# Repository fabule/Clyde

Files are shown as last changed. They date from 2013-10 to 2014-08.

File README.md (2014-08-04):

Clyde
======
Clyde is a lamp with a lot of personality that you can adapt, play with, and truly call your own. Clyde is open source and Arduino-compatible.  You can change how Clyde reacts to his environment by inserting personality modules on his main controller board. You can also change how Clyde behaves by reprogramming his firmware using the standard Arduino IDE.

For more information, see the website at: http://www.fabule.com or the forum at: http://fabule.com/forum/

To report a bug in the hardware or software, go to:
http://github.com/fabule/Clyde/issues

Installation
------------

The Clyde firmware is divided into three parts: bootloader, library, and sketch.

You can find the Clyde library in /software/arduino/libraries/. Place the "Clyde" library folder inside your Arduino "librairies" folder. This contains the majority of the code that controls Clyde. If you are not sure about how to install an Arduino library, you can find instructions here: http://arduino.cc/en/Guide/Libraries

When the library is in place, you can look for the sketch in /software/arduino/libraries/Clyde/Examples/ClydeOriginal. This sketch does not contain much, but it is a good place to start playing with Clyde's behaviors.

If you are using Windows, you'll need to install Clyde's driver. Find installers for 32-bit and 64-bit in /software/arduino/drivers/.  Double-click the driver that matches your needs.

Before you open your Arduino IDE, you'll need to copy one more folder. This step will add Clyde as a device under the "Tools > Board menu". First, if you do not have a "hardware" folder at the same level as your Arduino "librairies" folder, time to create one. Browse to the "hardware" folder in /software/arduino/hardware/ and open the subfolder that matches the version of your Arduino IDE, 1.0.5 or 1.5. Inside you'll find a "fabule" folder. Copy the "fabule" folder, inside the Arduino "hardware" folder you just created.

At this point, you should be ready to compile and upload Clyde's firmware. Connect Clyde to your computer using the USB cable.  Open the "ClydeFirmware" sketch in your Arduino IDE under "File > Examples > Clyde > ClydeOriginal" . Select Clyde under the "Tools > Board" menu, and the port assigned to Clyde under "Tools > Serial" Port. Press "Upload", and the firmware should compile and upload into Clyde.

If you want to make modifications to the bootloader, please refer to the information found here: https://github.com/fabule/Clyde/tree/master/software/arduino/bootloaders/caterina

Credits
-------
Clyde is an open source project manage by Fabule Fabrications in Montréal, Québec, Canada.

Clyde is based on the Arduino project, see the website at: http://arduino.cc

Arduino uses the GNU avr-gcc toolchain, avrdude, avr-libc, and code from
Processing and Wiring, LUFA, and i2cdevlib.

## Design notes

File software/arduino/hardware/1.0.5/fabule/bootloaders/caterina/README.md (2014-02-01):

Clyde Bootloader
================

How-To Compile
--------------
* Download and extract LUFA: https://code.google.com/p/lufa-lib/downloads/detail?name=LUFA-111009.zip&can=2&q=
* Set your LUFA directory in the Makefile.
* Run: make clyde

How-To Program
--------------
* Set your AVRDUDE_PROGRAMMER and AVRDUDE_PORT in the Makefile
* Run: make program
* (on Windows) You'll need to point to the .inf file found in /software/arduino/drivers

Changes
-------
* Added "Fabule" and "Clyde" to the USB descriptor strings of Descriptor.c
* Added a "clyde" target to the Makefile to speed up the compiling process
* Changed the "program" target of the Makefile to accept product ids for hex file selection

Attribution
-----------
This Clyde bootloader is based on the Arduino Caterina bootloader in release 1.0.5 found at:
https://github.com/arduino/Arduino/releases/tag/1.0.5

This bootloader, just like the original Caterina, uses the LUFA library found at:
https://code.google.com/p/lufa-lib/
more specifically, it was tested with the "111009" release of LUFA found at:
https://code.google.com/p/lufa-lib/downloads/detail?name=LUFA-111009.zip&can=2&q=

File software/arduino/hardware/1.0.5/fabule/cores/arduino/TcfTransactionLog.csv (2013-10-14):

Service | Message | Max | Min | Average | Count | frequency | TimedOut
Stream | setLogBits | 458 | 79 | 268.5 | 2 | 0

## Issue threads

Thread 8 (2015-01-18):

Mouth?

bruno-c, 2015-01-18:
Hello,

I see a bunch of references to a Clyde loud mouth in the code! I assume this is a feature that didn't make it into Mark 1, but would it be hard to add some kind of audio output to Clyde? I don't have any experience with Arduino, though I have plenty of programming experience.

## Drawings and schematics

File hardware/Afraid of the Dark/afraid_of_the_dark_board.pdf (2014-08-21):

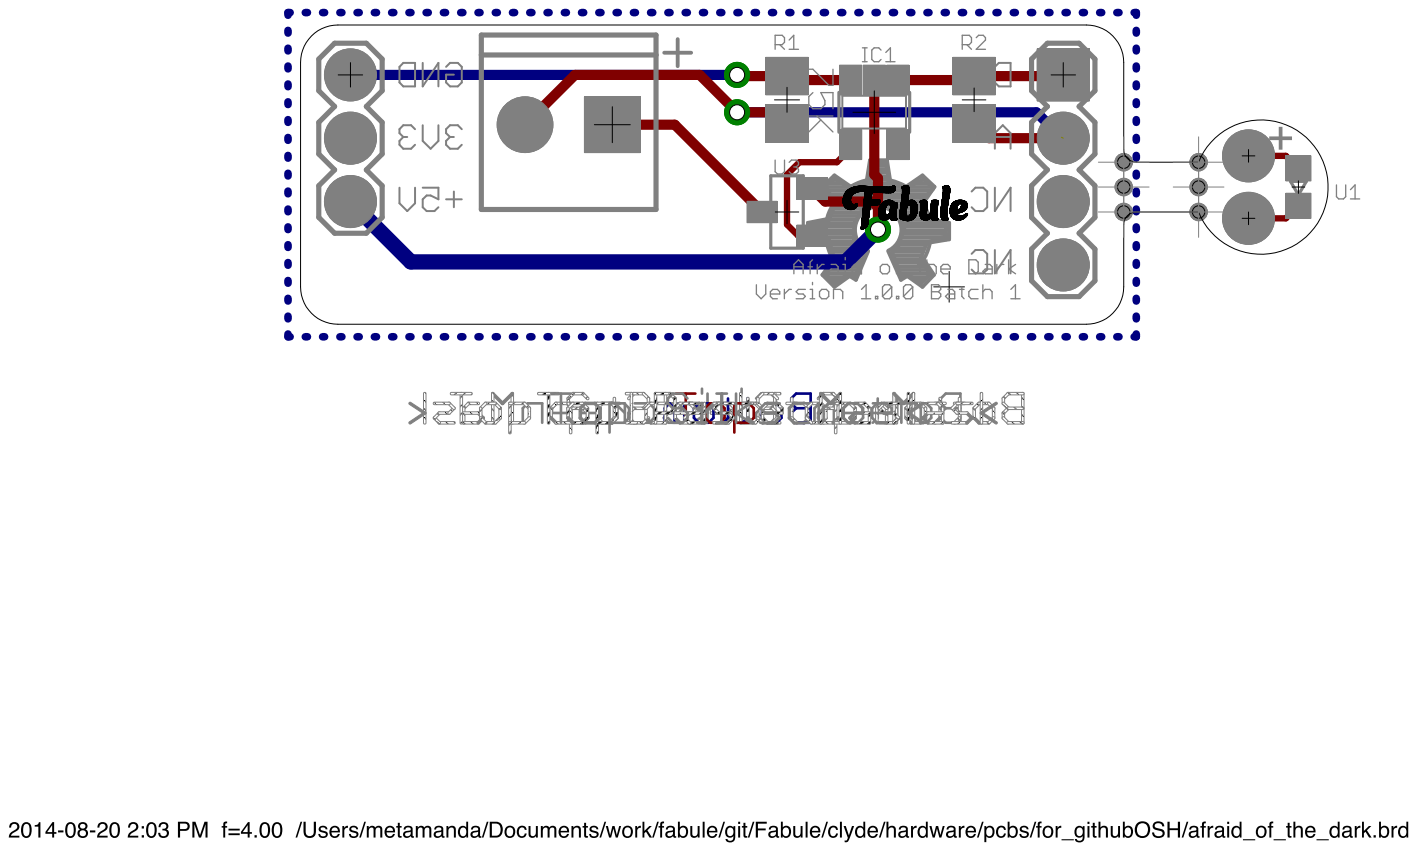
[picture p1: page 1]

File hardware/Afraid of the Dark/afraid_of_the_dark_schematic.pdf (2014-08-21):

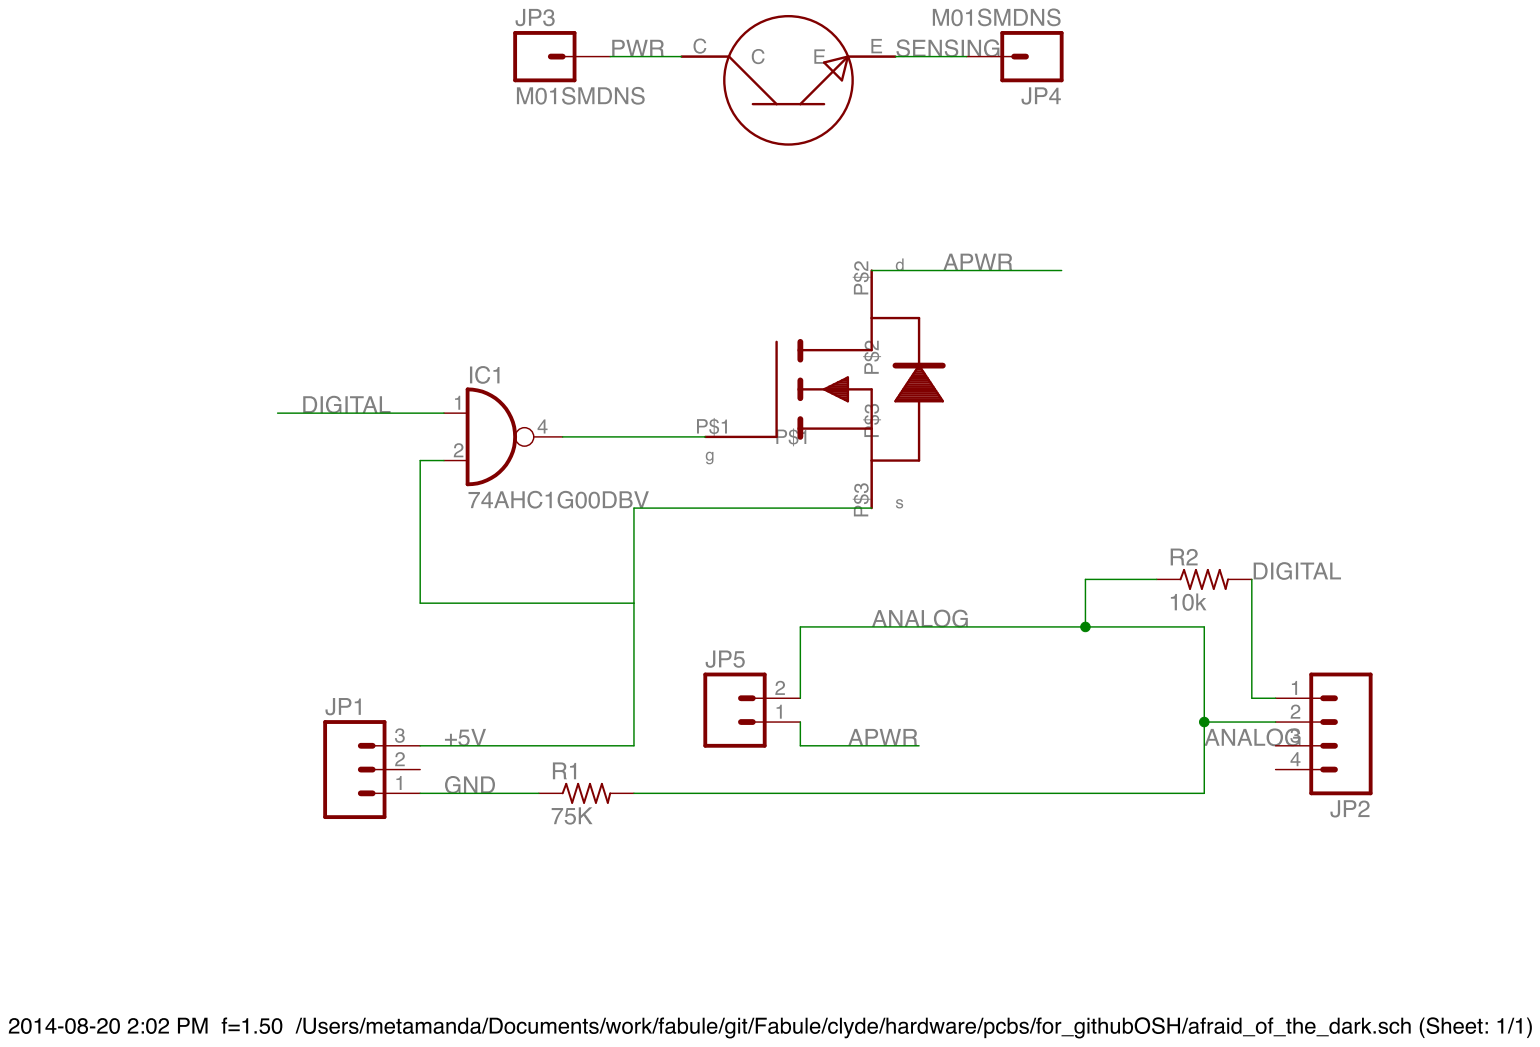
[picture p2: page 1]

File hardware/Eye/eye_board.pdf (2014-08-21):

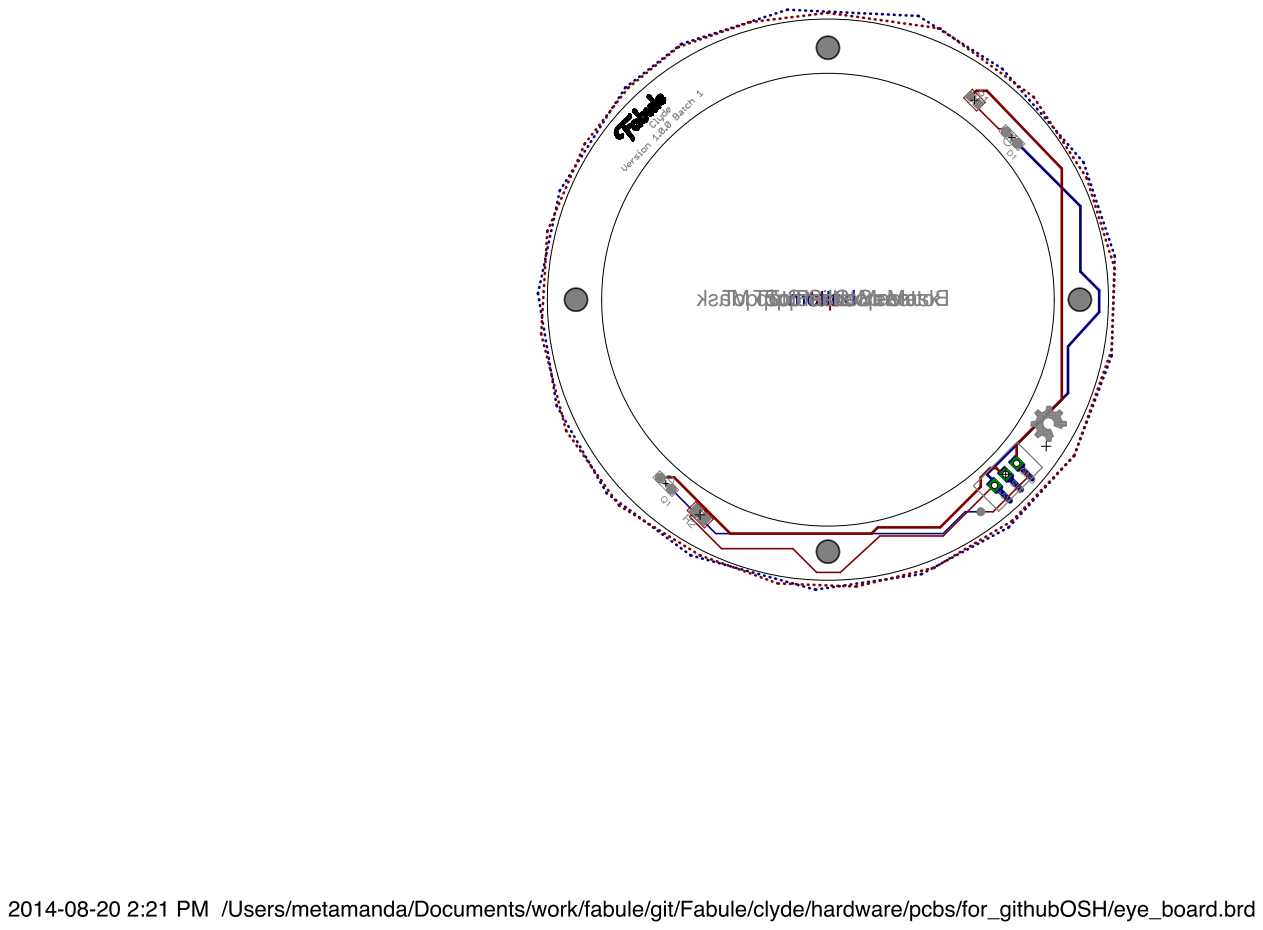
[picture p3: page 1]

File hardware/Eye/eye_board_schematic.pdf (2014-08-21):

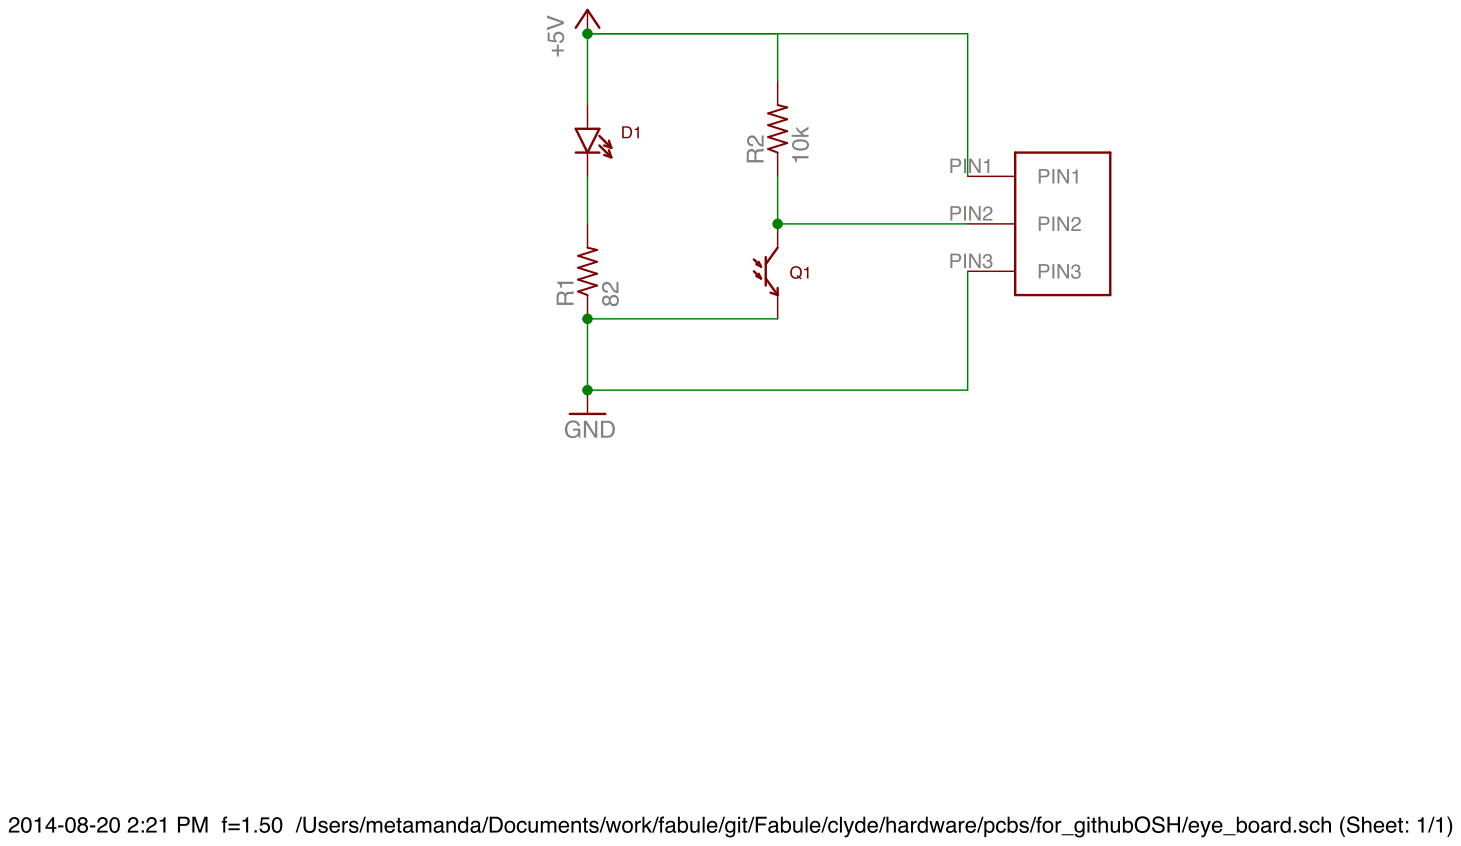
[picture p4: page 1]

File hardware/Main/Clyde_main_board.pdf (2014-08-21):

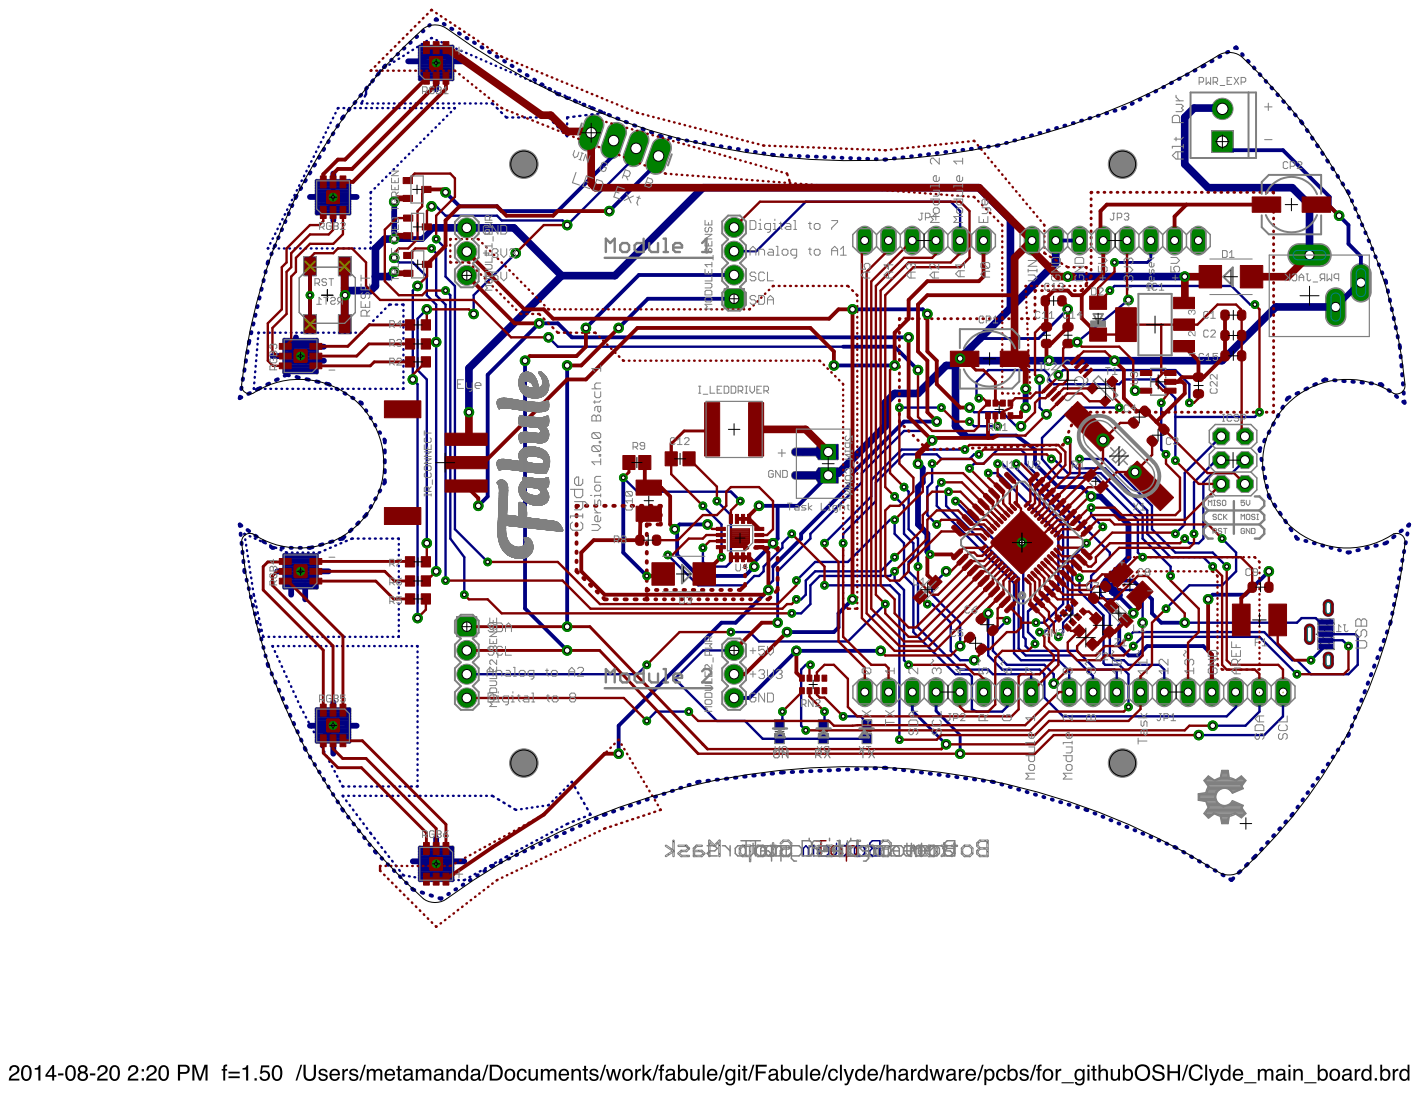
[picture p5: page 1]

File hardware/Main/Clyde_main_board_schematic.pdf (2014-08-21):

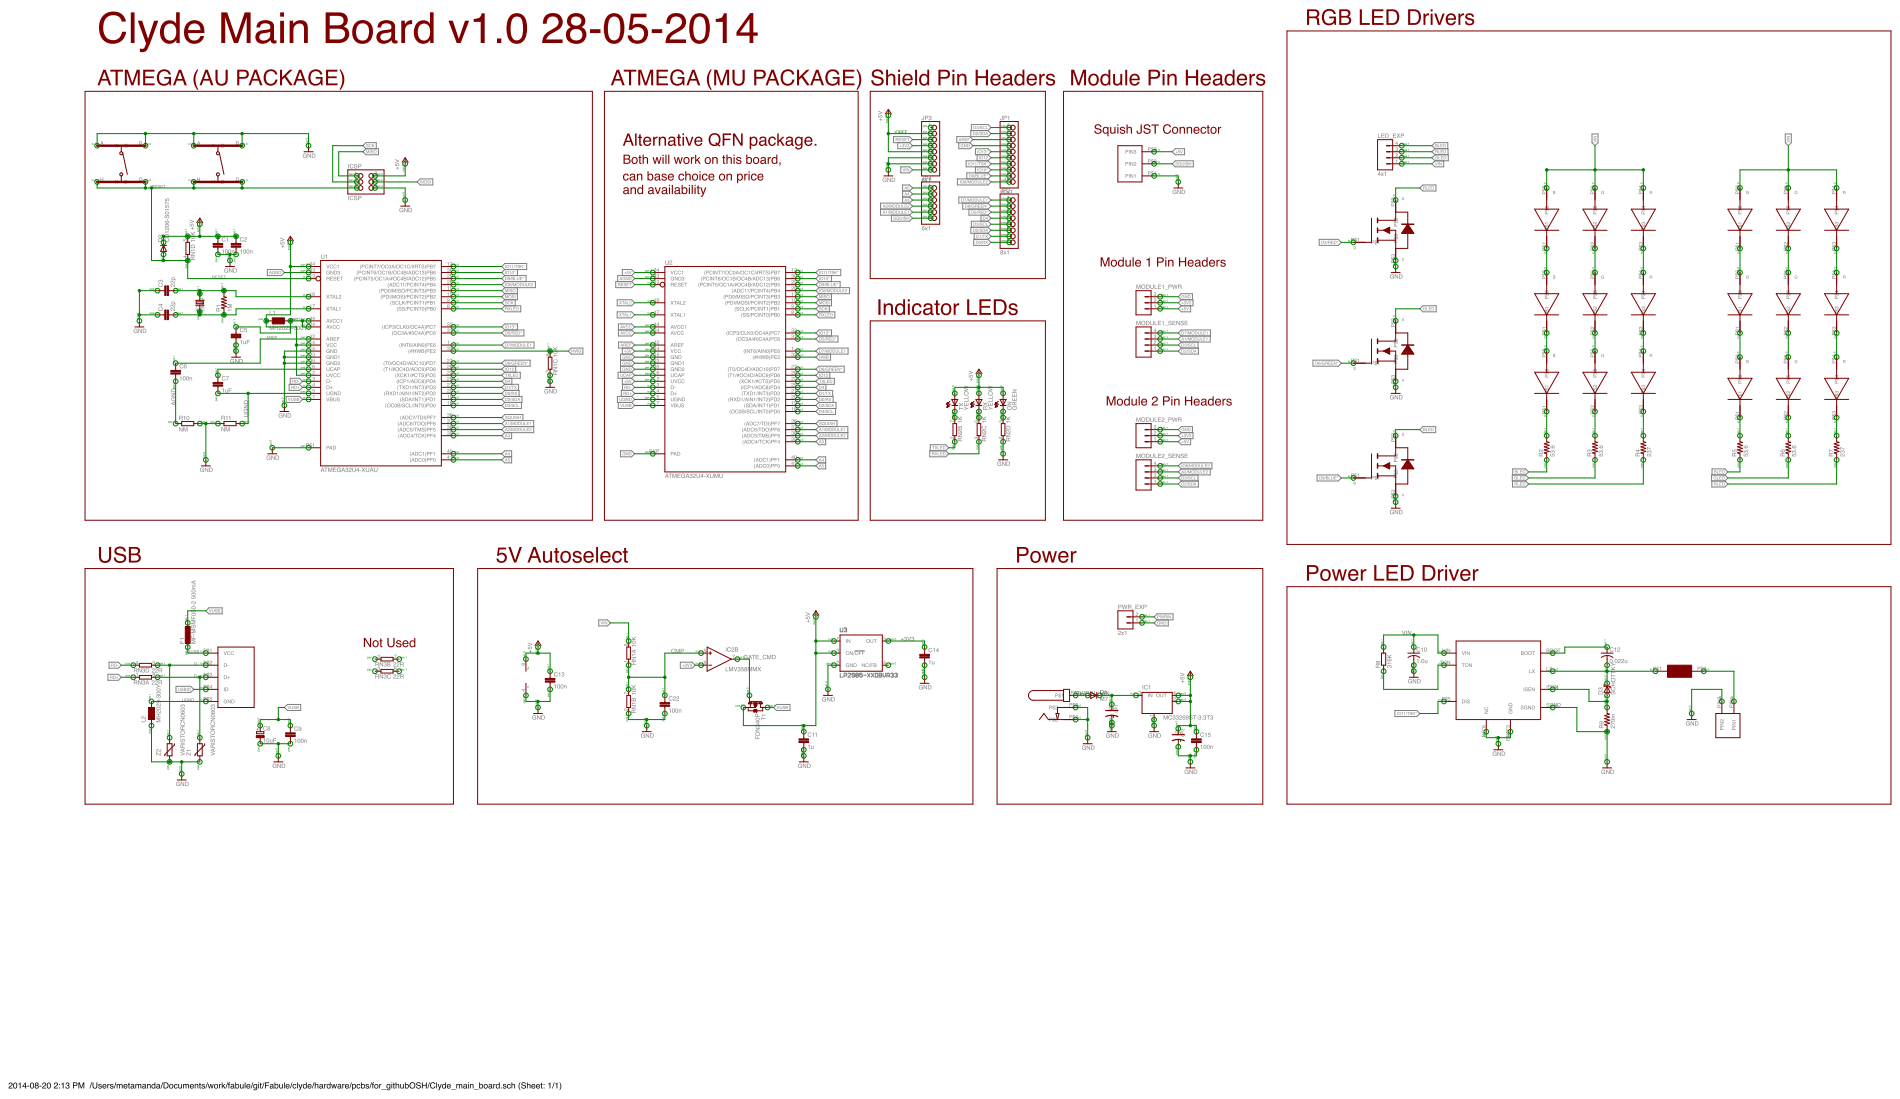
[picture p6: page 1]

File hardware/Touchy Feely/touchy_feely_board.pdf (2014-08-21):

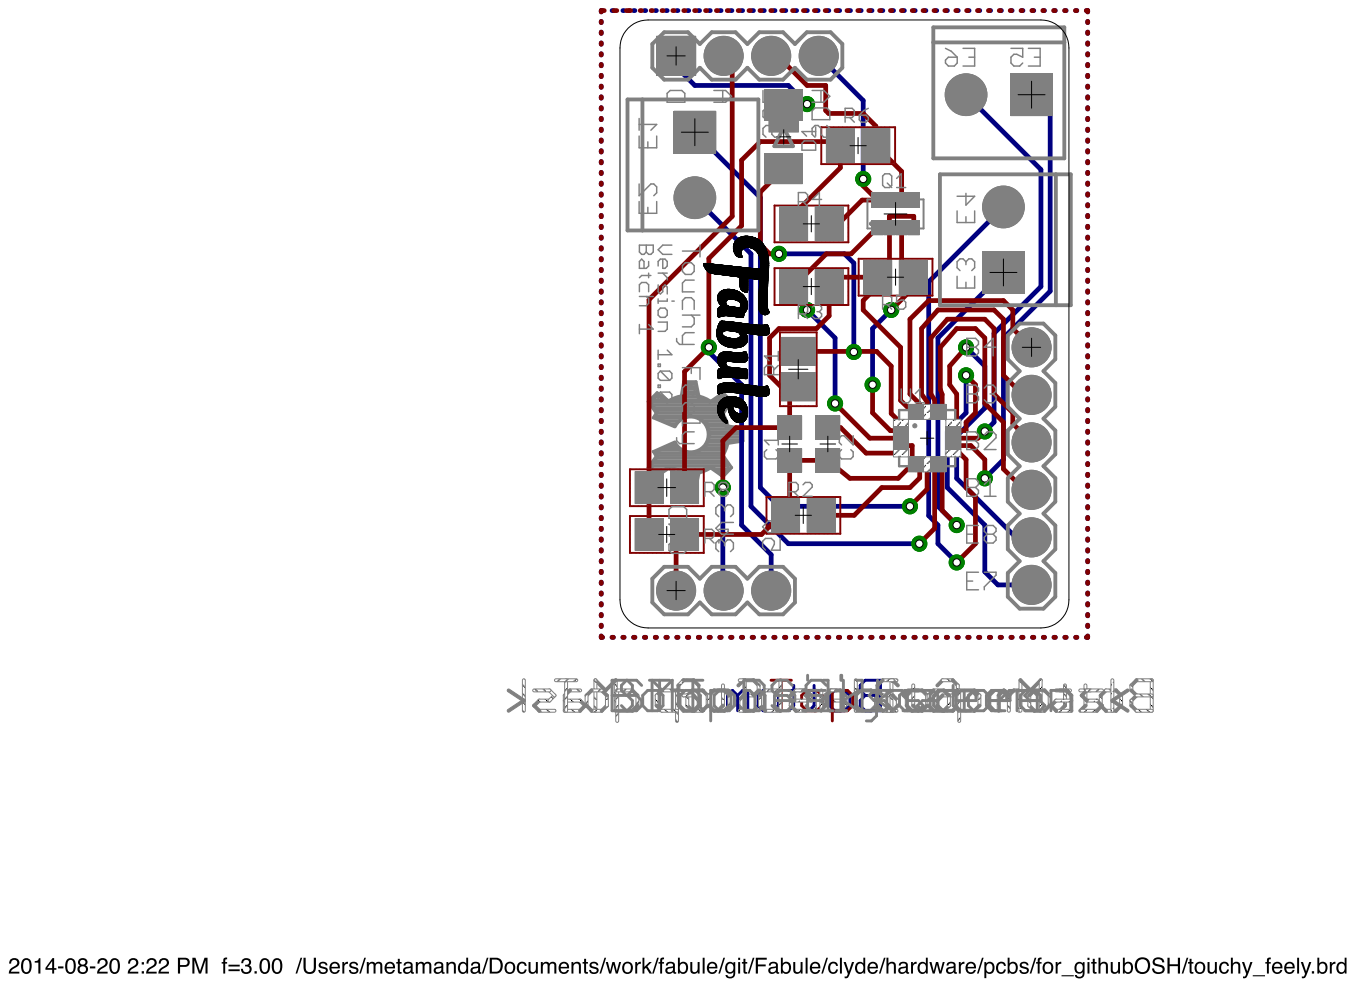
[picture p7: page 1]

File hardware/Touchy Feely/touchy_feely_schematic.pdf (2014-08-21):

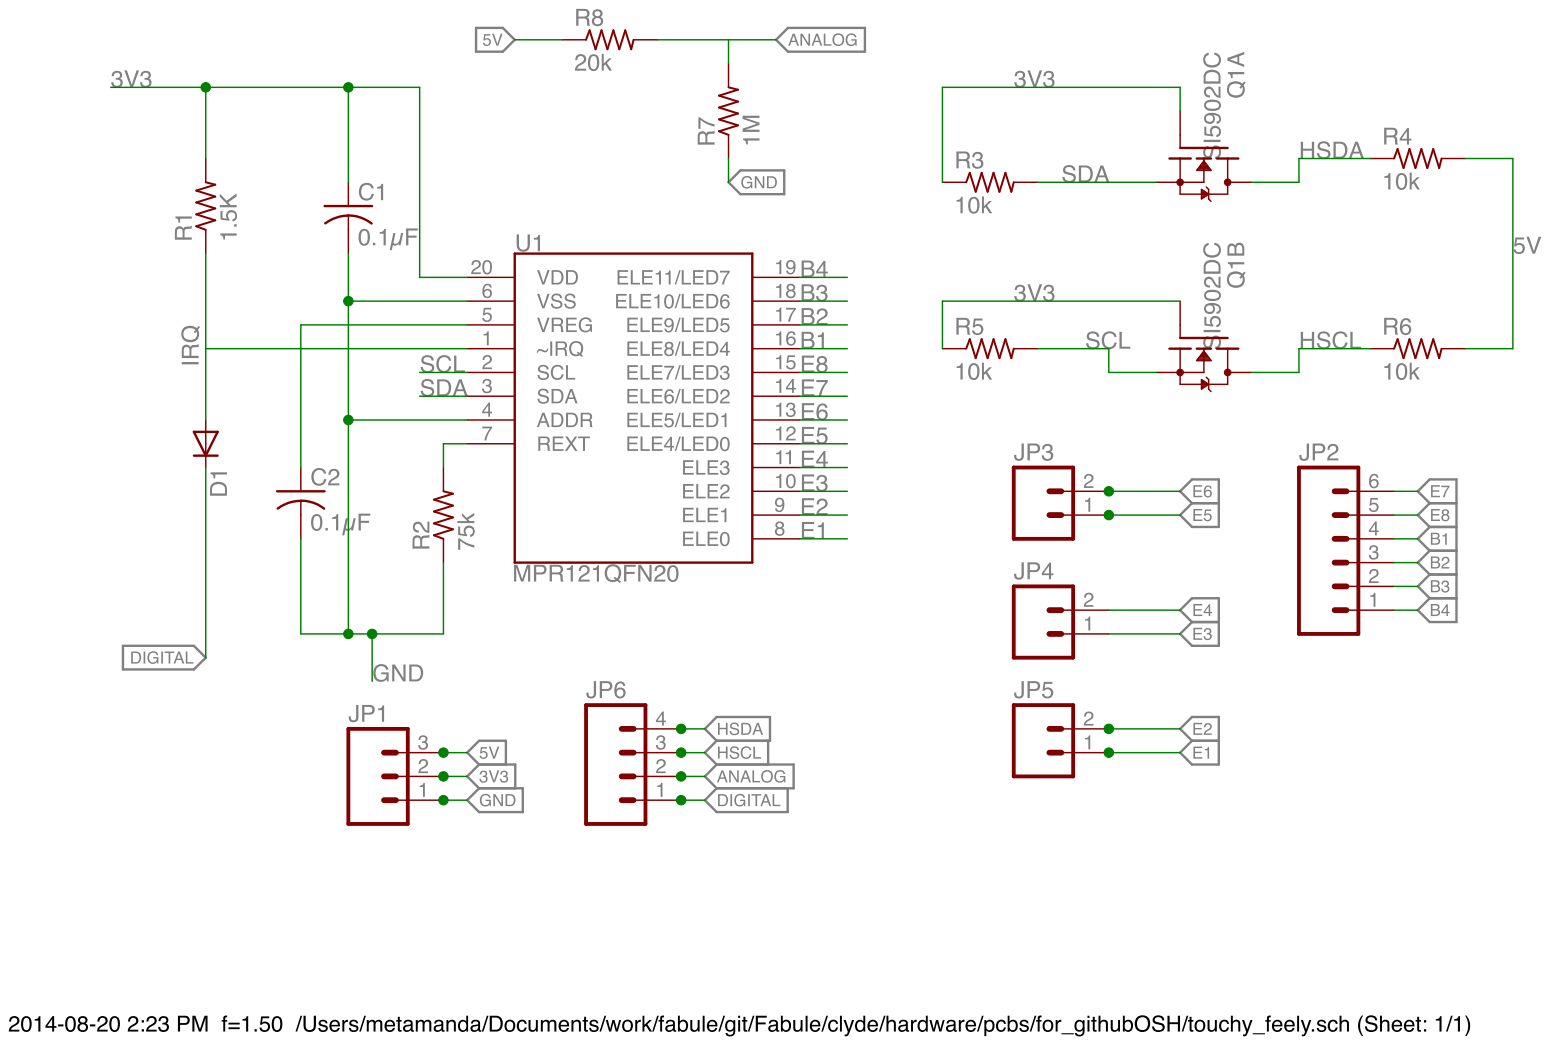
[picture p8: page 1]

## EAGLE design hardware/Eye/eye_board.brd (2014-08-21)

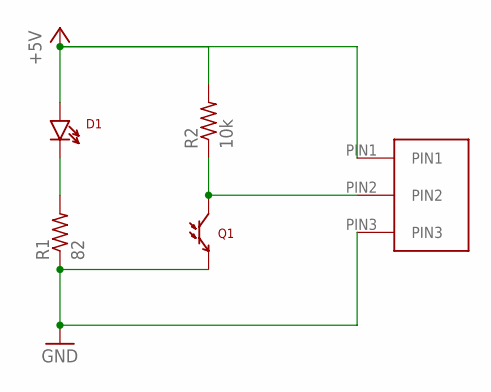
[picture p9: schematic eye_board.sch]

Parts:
3PIN_CONN: XH_JST_CONN_3POS_TOP
D1: LTE-302
Q1: LTR-301
R1: 82; R0603
R2: 10k; R0805

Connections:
+5V: 3PIN_CONN.PIN1, D1.A, R2.2
GND: 3PIN_CONN.PIN3, Q1.E, R1.1
unnamed: D1.C, R1.2
unnamed: 3PIN_CONN.PIN2, Q1.C, R2.1

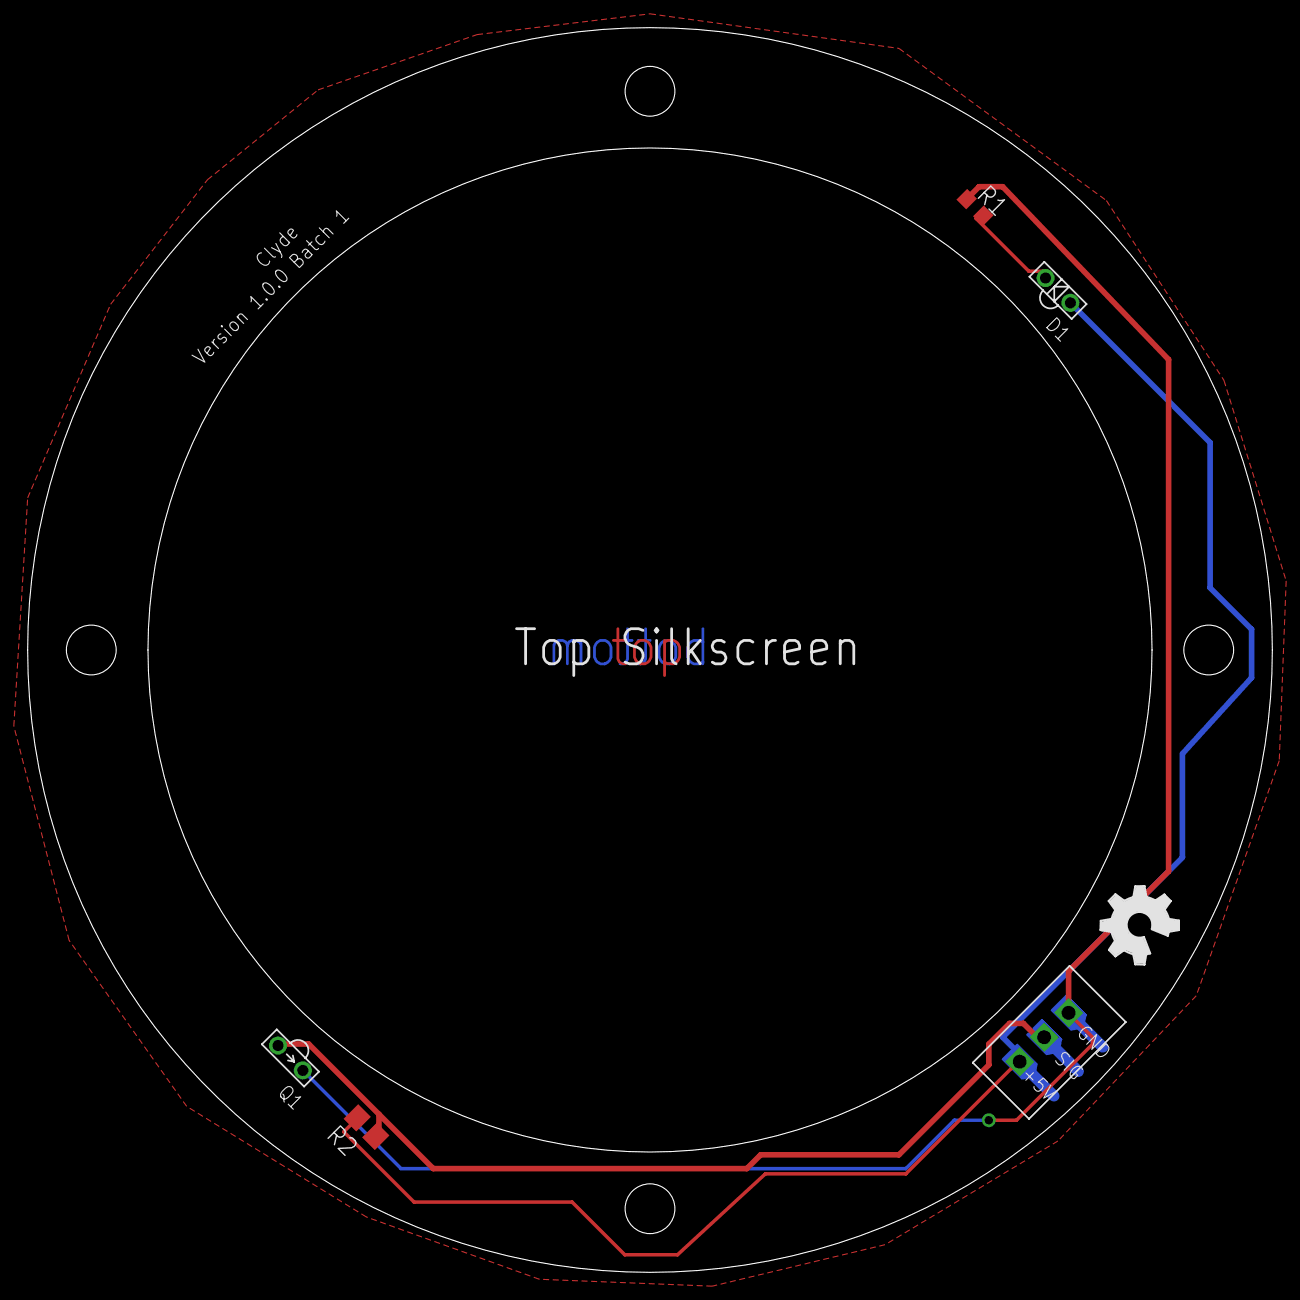
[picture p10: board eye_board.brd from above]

Board: 2 copper layers, 90.0 x 90.0 mm, 6 parts (0 on the bottom side), 4 nets.

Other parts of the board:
U$2: OSHW_FILLX200_NOTEXT

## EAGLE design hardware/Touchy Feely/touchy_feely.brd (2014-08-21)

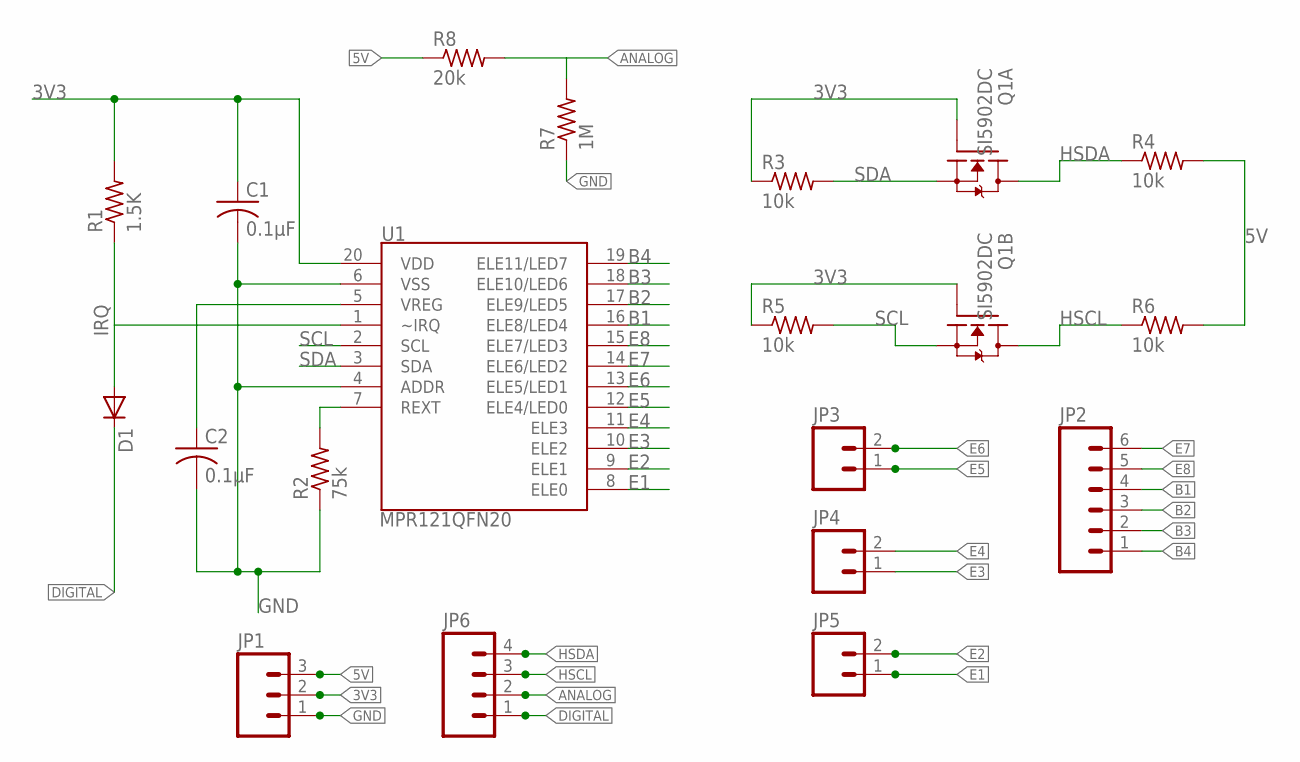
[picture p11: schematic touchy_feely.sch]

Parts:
C1, C2: 0.1µF; C0603K
D1: DIODE-MINIMELF; MINIMELF
JP1: M03PTH; 1X03
JP2: M06SIP; 1X06
JP3, JP4, JP5: M023.5MM; SCREWTERMINAL-3.5MM-2
JP6: M04PTH; 1X04
Q1: SI5902DC; 1206-8CHIP-FET
R1: 1.5K; M0805
R2: 75k; M0805
R3, R4, R5, R6: 10k; M0805
R7: 1M; R0805
R8: 20k; R0805
U1: MPR121QFN20; QFN-20-0.4MM

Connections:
3V3: C1.1, JP1.2, Q1.2 (G), Q1.4 (G), R1.2, R3.1, R5.1, U1.20 (VDD)
5V: JP1.3, R4.2, R6.2, R8.1
ANALOG: JP6.2, R7.2, R8.2
B1: JP2.4, U1.16 (ELE8/LED4)
B2: JP2.3, U1.17 (ELE9/LED5)
B3: JP2.2, U1.18 (ELE10/LED6)
B4: JP2.1, U1.19 (ELE11/LED7)
DIGITAL: D1.C, JP6.1
E1: JP5.1, U1.8 (ELE0)
E2: JP5.2, U1.9 (ELE1)
E3: JP4.1, U1.10 (ELE2)
E4: JP4.2, U1.11 (ELE3)
E5: JP3.1, U1.12 (ELE4/LED0)
E6: JP3.2, U1.13 (ELE5/LED1)
E7: JP2.6, U1.14 (ELE6/LED2)
E8: JP2.5, U1.15 (ELE7/LED3)
GND: C1.2, C2.2, JP1.1, R2.1, R7.1, U1.4 (ADDR), U1.6 (VSS)
HSCL: JP6.3, Q1.5 (D), Q1.6 (D), R6.1
HSDA: JP6.4, Q1.7 (D), Q1.8 (D), R4.1
IRQ: D1.A, R1.1, U1.1 (~IRQ)
unnamed: C2.1, U1.5 (VREG)
unnamed: R2.2, U1.7 (REXT)
SCL: Q1.3 (S), R5.2, U1.2 (SCL)
SDA: Q1.1 (S), R3.2, U1.3 (SDA)

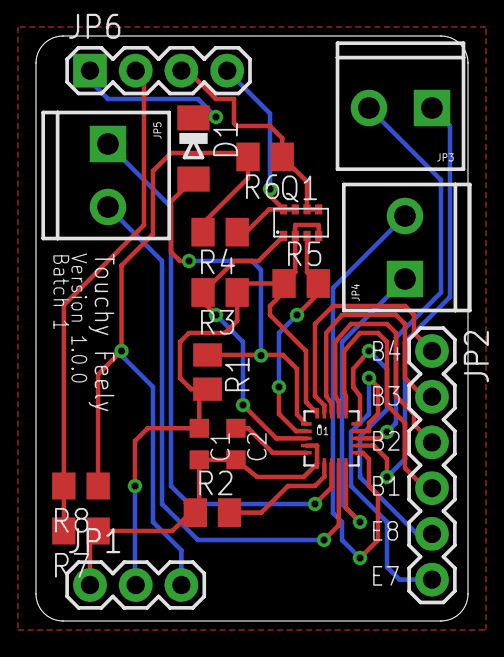
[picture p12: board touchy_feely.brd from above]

Board: 2 copper layers, 24.0 x 32.5 mm, 20 parts (1 on the bottom side), 24 nets.

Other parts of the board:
U$2: OSHW_FILLX200_NOTEXT

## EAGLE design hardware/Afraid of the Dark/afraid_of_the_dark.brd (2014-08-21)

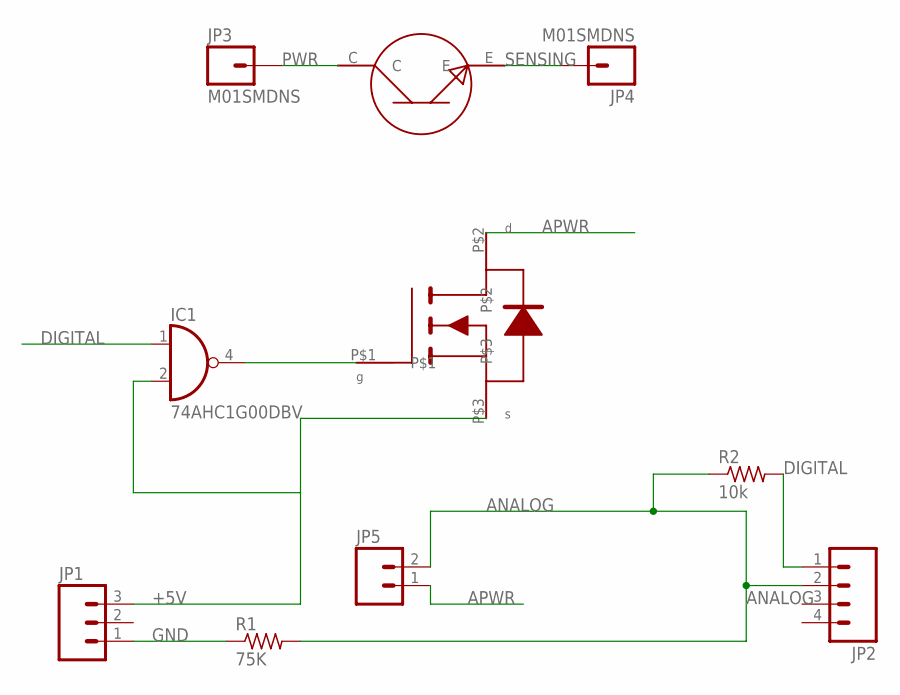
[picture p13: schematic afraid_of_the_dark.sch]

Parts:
IC1: 74AHC1G00DBV; SOT23-5
JP1: M03PTH; 1X03
JP2: M04PTH; 1X04
JP3, JP4: M01SMDNS; 1X01NS
JP5: M023.5MM; SCREWTERMINAL-3.5MM-2
R1: 75K; R0805
R2: 10k; R0805
U1: AMBIENT_LIGHT_SENSOR
U3: SI2302DS_MOSFET

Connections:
+5V: IC1.2 (I1), JP1.3, U3.P$3
ANALOG: JP2.2, JP5.2, R1.2, R2.1
APWR: JP5.1, U3.P$2
DIGITAL: IC1.1 (I0), JP2.1, R2.2
GND: IC1.3 (GND), JP1.1, R1.1
unnamed: IC1.4 (O), U3.P$1
PWR: JP3.1, U1.C
SENSING: JP4.1, U1.E
VCC: IC1.5 (VCC)

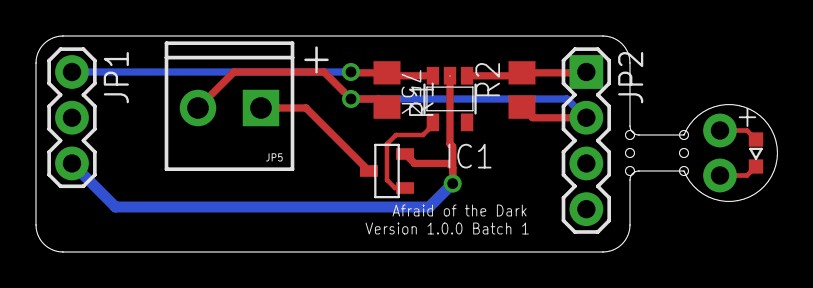
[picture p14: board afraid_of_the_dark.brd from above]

Board: 2 copper layers, 41.2 x 12.0 mm, 11 parts (1 on the bottom side), 8 nets.

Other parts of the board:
U$2: OSHW_FILLX200_NOTEXT

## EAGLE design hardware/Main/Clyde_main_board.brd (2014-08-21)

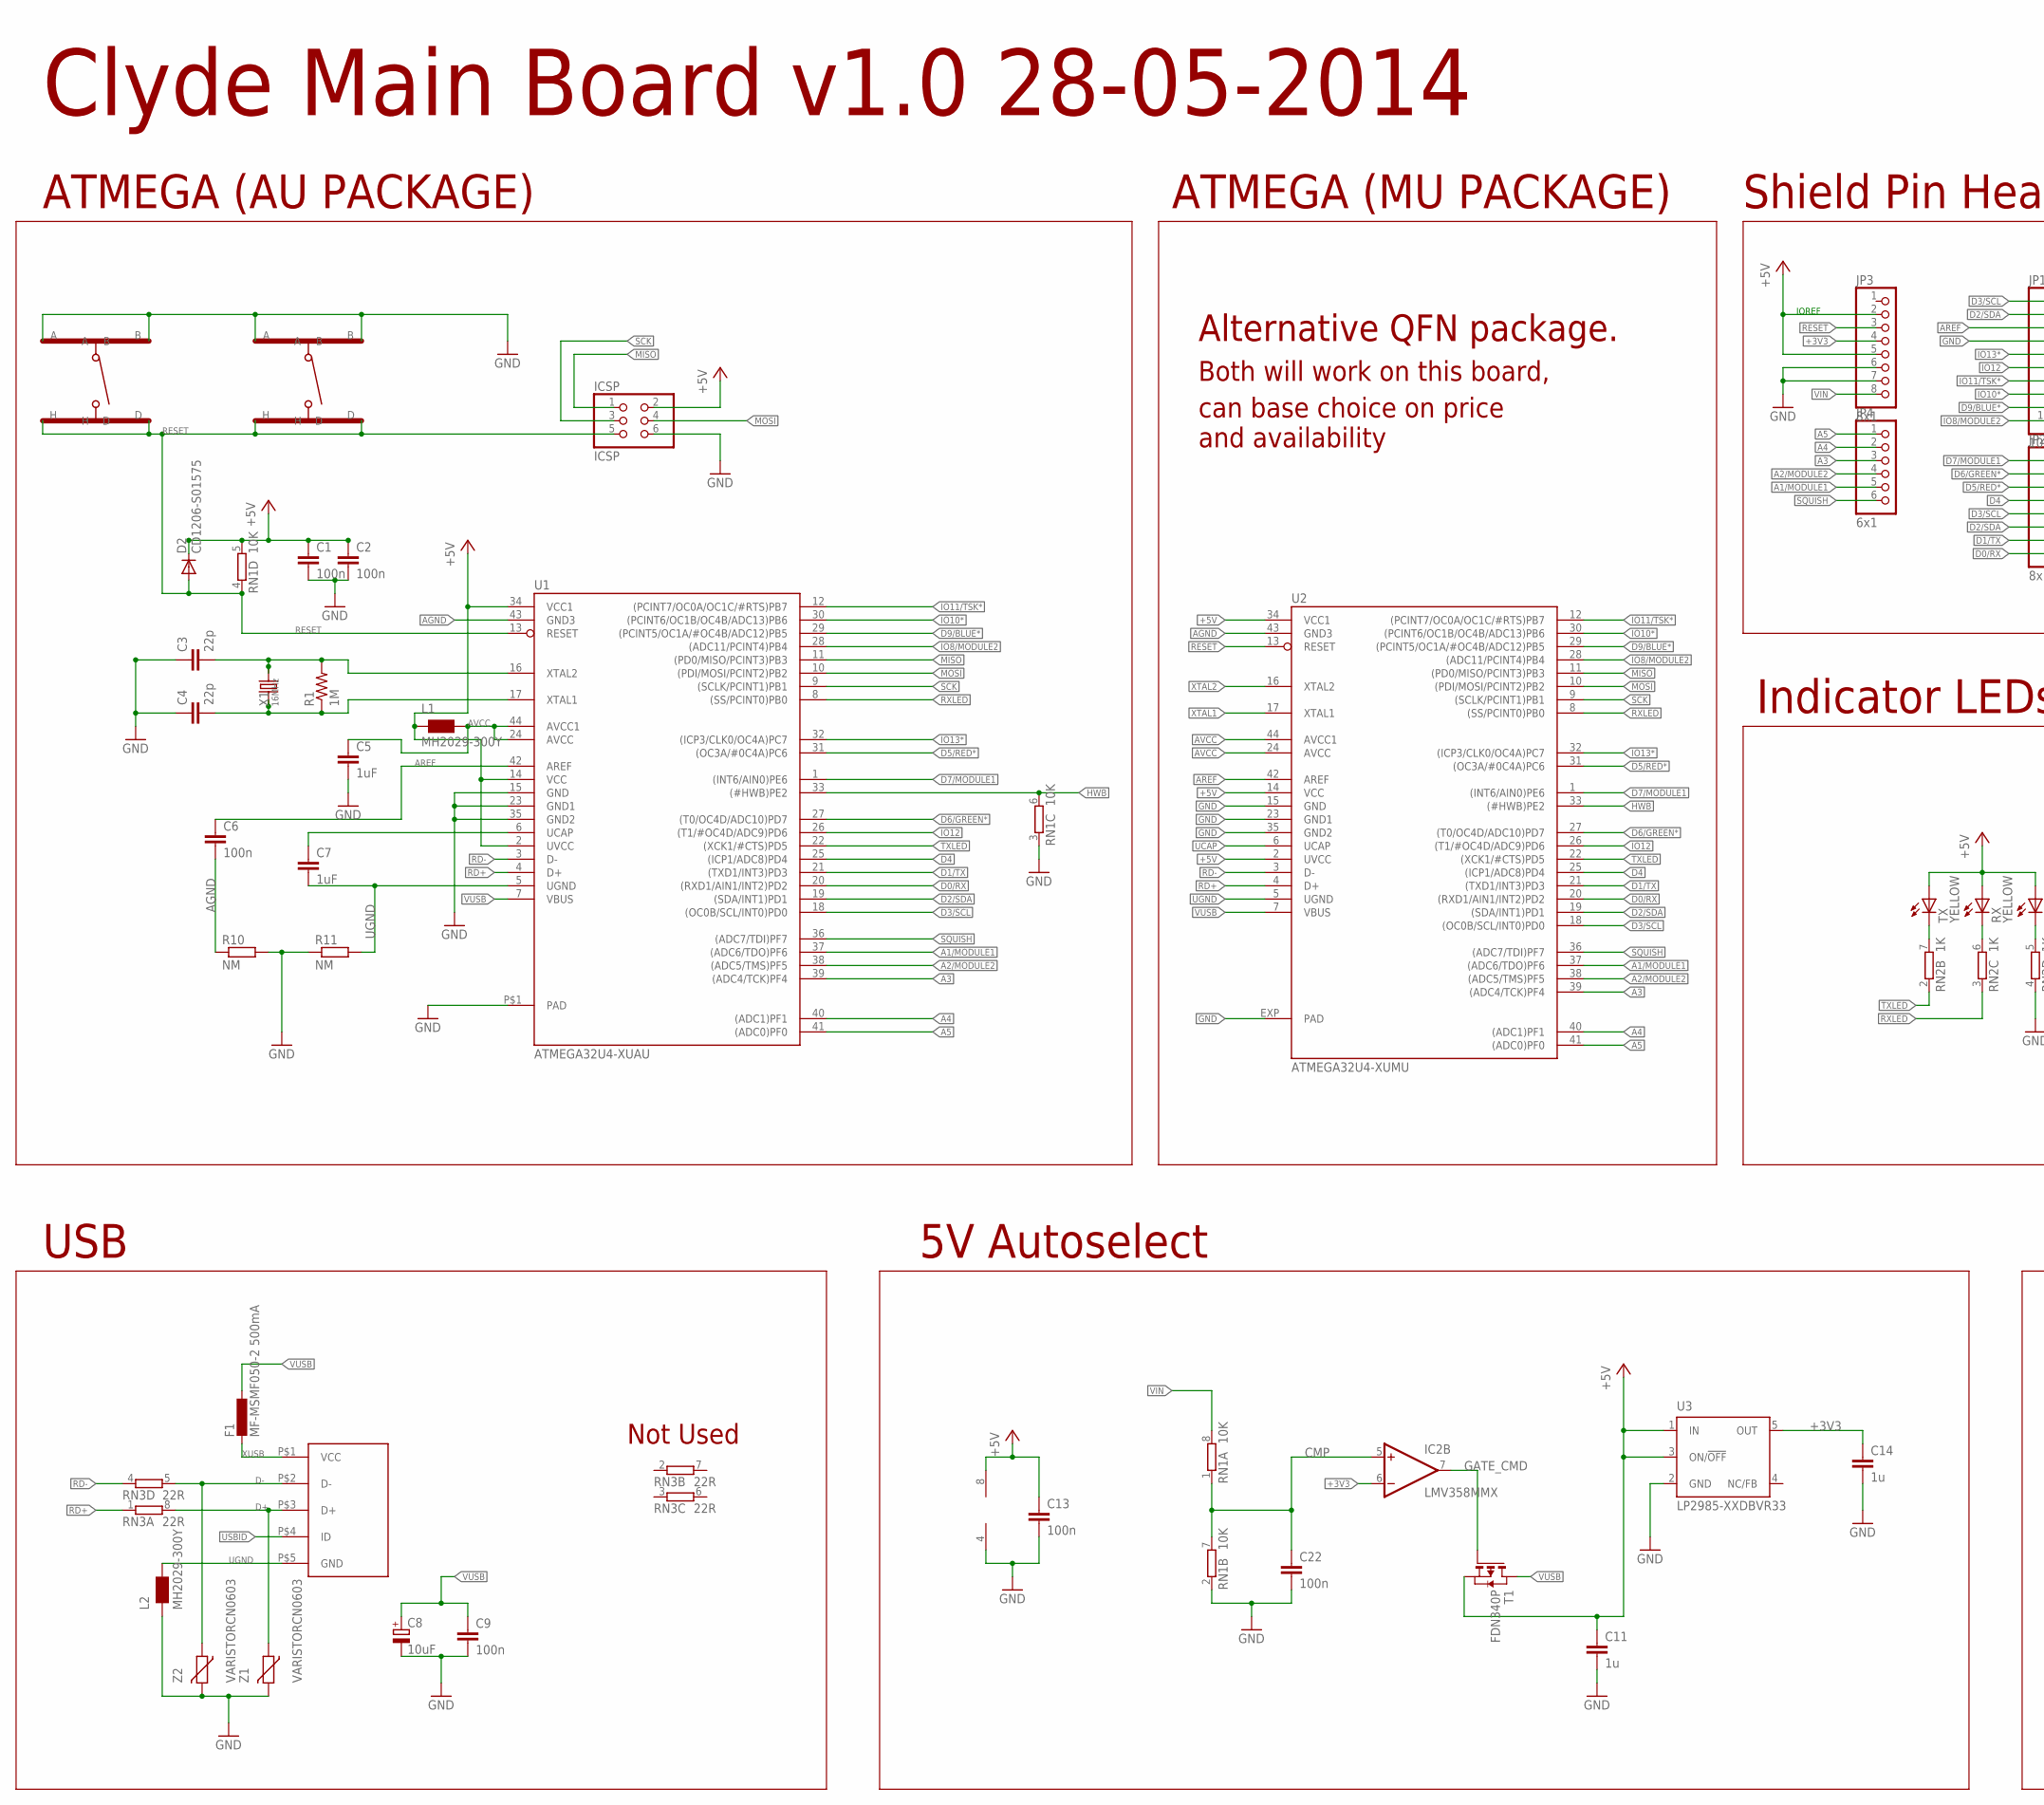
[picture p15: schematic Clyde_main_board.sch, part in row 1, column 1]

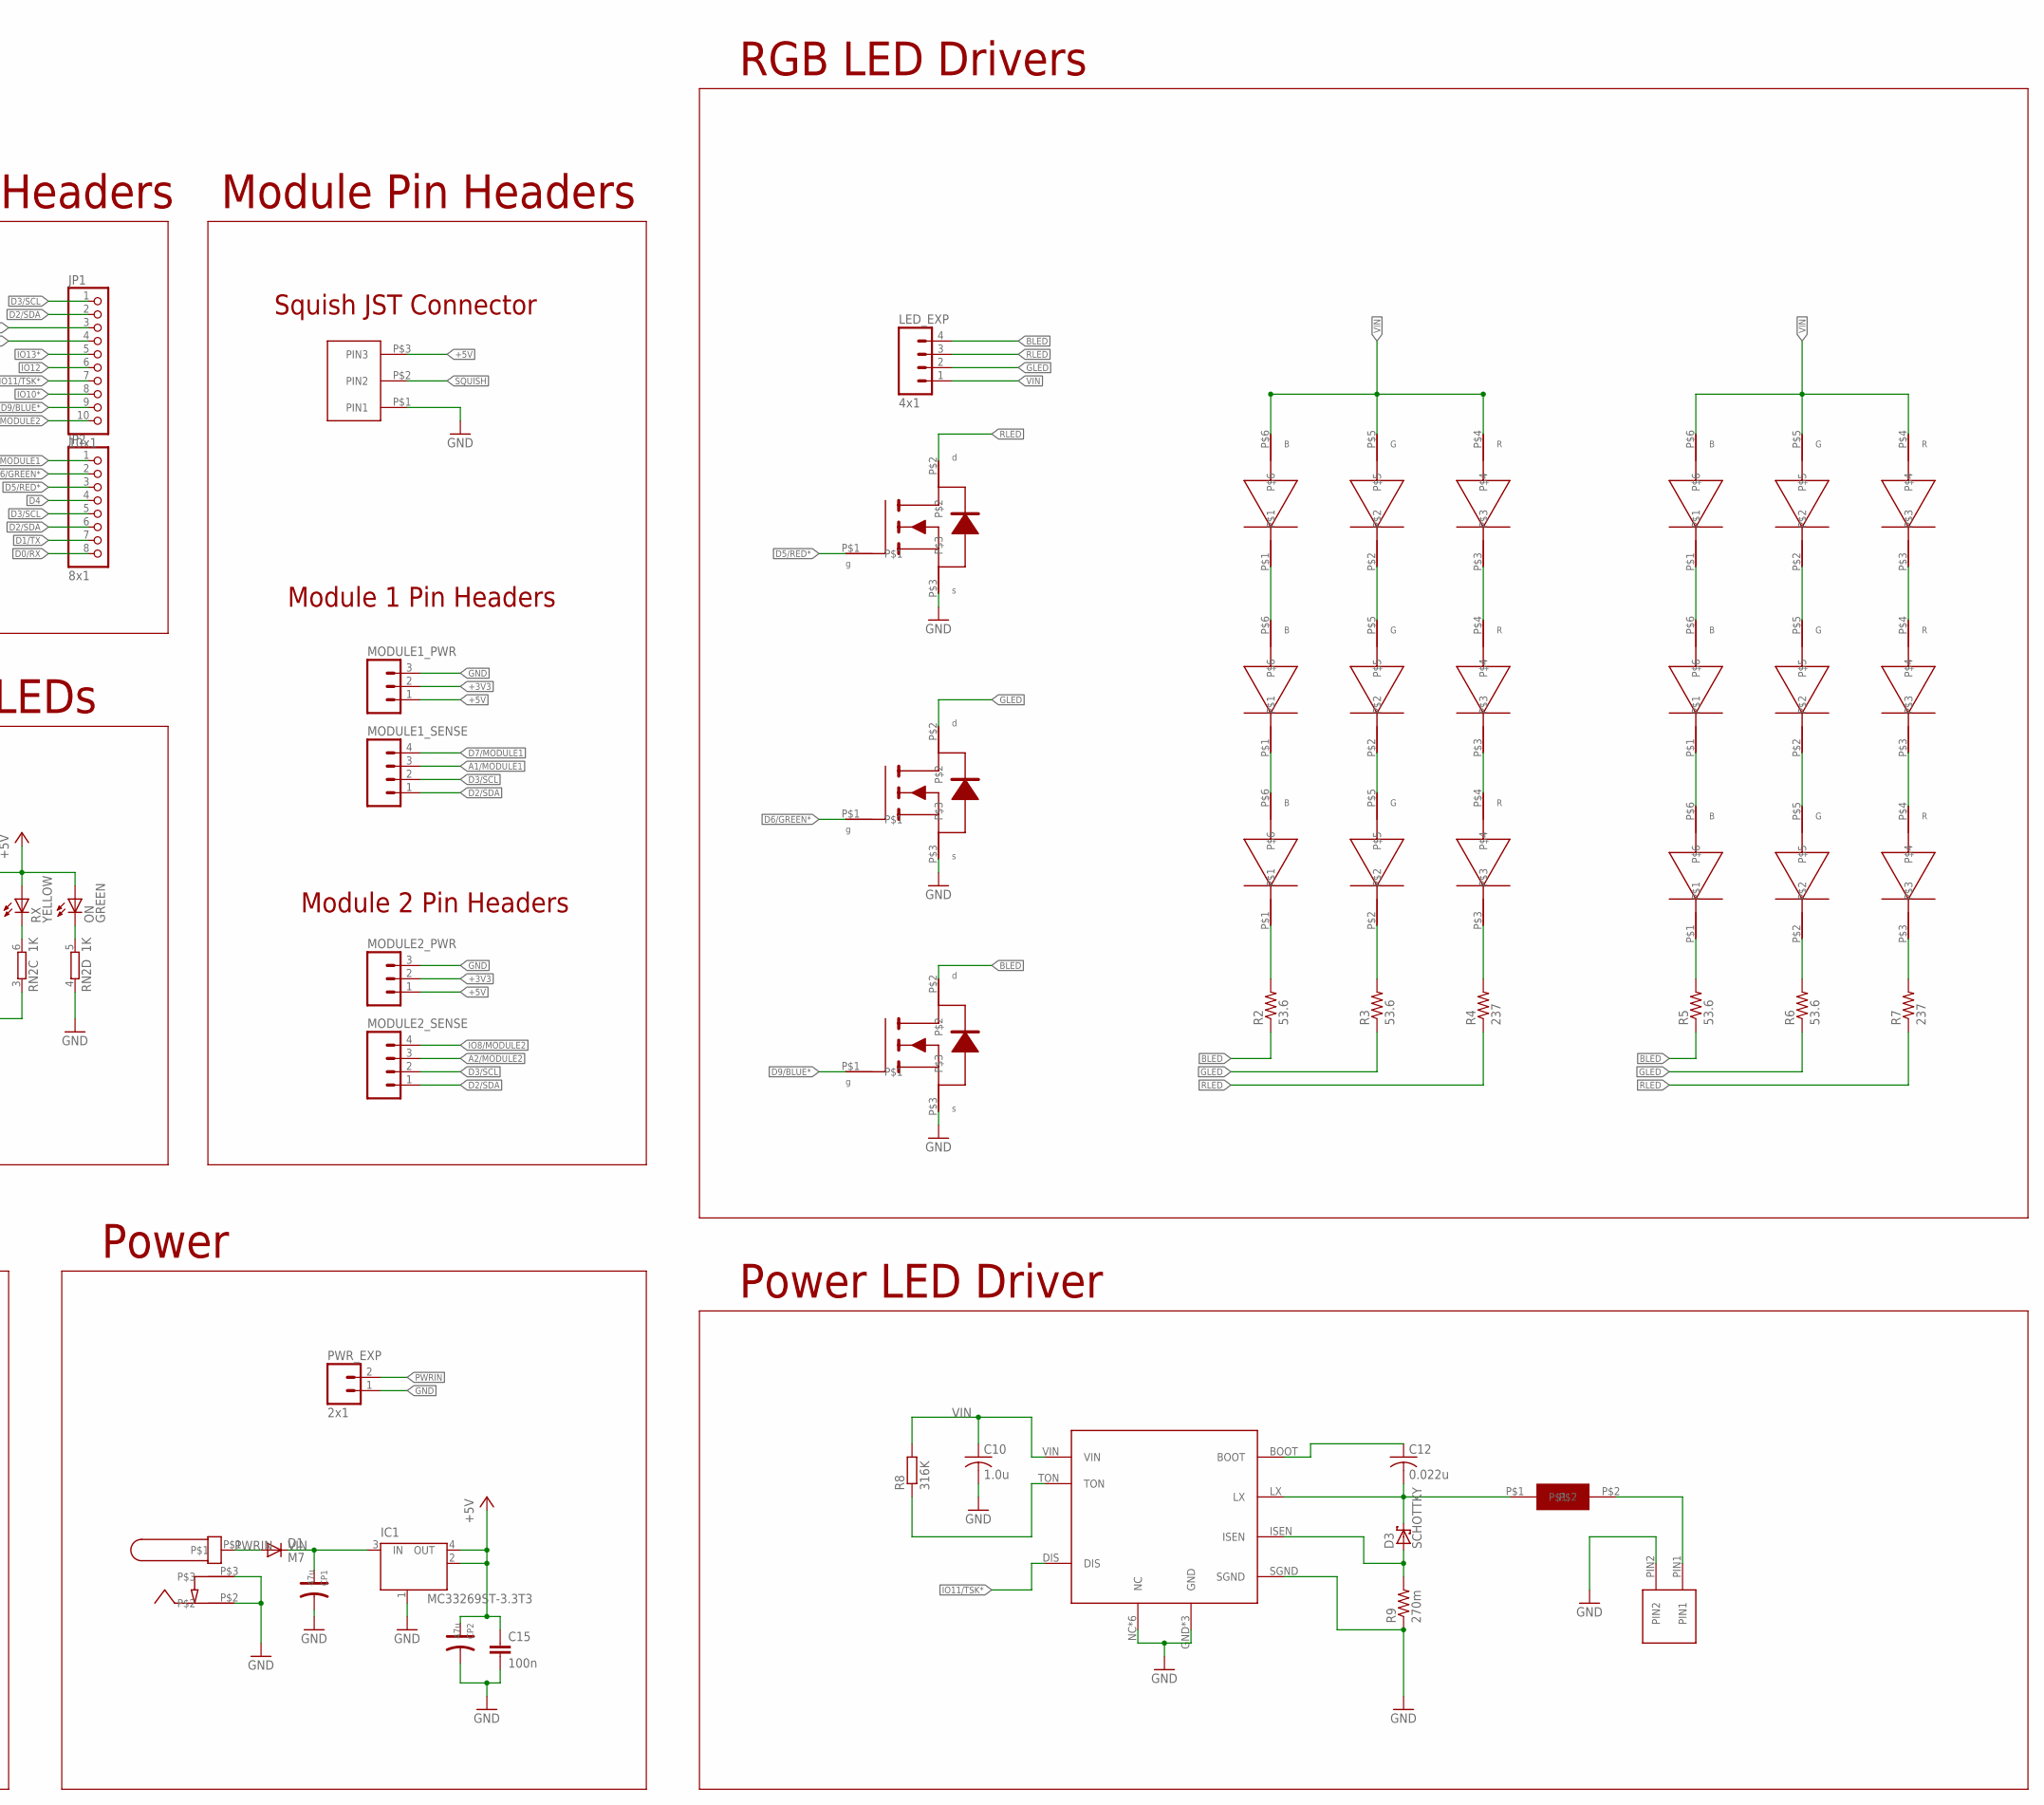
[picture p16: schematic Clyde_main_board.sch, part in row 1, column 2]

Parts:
2PIN_CONN: XH_JST_CONN_2POS_TOP
C1, C2, C6, C9, C13, C15, C22: 100n; C0603-ROUND
C3, C4: 22p; C0603-ROUND
C5, C7: 1uF; C0603-ROUND
C8: 10uF; SMC_B
C10: 1.0u; C1210
C11, C14: 1u; C0603-ROUND
C12: 0.022u; C0805
CP1, CP2: 47u; ELECTRO-SMD-C-6MM
D1: M7; SMB
D2: CD1206-S01575; MINIMELF
D3: SCHOTTKY; SMB
F1: MF-MSMF050-2 500mA; L1812
IC1: MC33269ST-3.3T3; SOT223
IC2: LMV358MMX; MSOP08
ICSP: ICSP; 2X03
IR_CONNECT: XH_JST_CONN_3POS_SIDE_SMT
I_LEDDRIVER: TAIYO_YUDEN_6045_INDUCTOR
J1: MOLEX_VERT_MINIUSB
JP1: 10x1; 1X10
JP2, JP3: 8x1; 1X08
JP4: 6x1; 1X06
L1, L2: MH2029-300Y; 0805
LED_EXP: 4x1; 1X04_LONGPADS
MODULE1_PWR, MODULE2_PWR: M03PTH; 1X03
MODULE1_SENSE, MODULE2_SENSE: M04PTH; 1X04
ON: GREEN; CHIPLED_0603
PWR_EXP: 2x1; SCREWTERMINAL-3.5MM-2
PWR_JACK: VERT_PWRJACK_PJ-006A_CUIINC
R1: 1M; 0805
R2, R3, R5, R6: 53.6; R0603
R4, R7: 237; R0603
R8: 316K; R0603-ROUND
R9: 270m; R0805
R10, R11: NM; R0402_NM
RGB1, RGB2, RGB3, RGB4, RGB5, RGB6: HANGZHOU_MULTICOLOR_3535WSA; HANGZHOU_MULTCOLOR_3535WSZ
RN1: 10K; CAY16
RN2: 1K; CAY16
RN3: 22R; CAY16
RST, RST1: COMAX_MINISWITCH
RX: YELLOW; CHIPLED_0603
T1: FDN340P; SOT-23
TBLUE: SI2302DS_MOSFET
TGREEN: SI2302DS_MOSFET
TRED: SI2302DS_MOSFET
TX: YELLOW; CHIPLED_0603
U1: ATMEGA32U4-XUAU; TQFP44-PAD
U2: ATMEGA32U4-XUMU; QFN44ML7X7
U3: LP2985-XXDBVR33; SOT23-DBV
U4: ALLEGRO_A6210
X1: 16MHz; XTAL_THRU_SMT
Z1, Z2: VARISTORCN0603; CT/CN0603

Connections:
+3V3: C14.1, IC2.6 (-IN), JP3.4, MODULE1_PWR.2, MODULE2_PWR.2, U3.5 (OUT)
+5V: C1.1, C2.1, C11.1, C13.1, C15.1, CP2.+, D2.C, IC1.2 (OUT), IC1.4 (OUT), IC2.8 (V+), ICSP.2, IR_CONNECT.P$3 (PIN3), JP3.2, JP3.5, L1.1, MODULE1_PWR.1, MODULE2_PWR.1, ON.A, RN1.5 (2), RX.A, T1.2 (S), TX.A, U1.2 (UVCC), U1.14 (VCC), U1.34 (VCC1), U2.2 (UVCC), U2.14 (VCC), U2.34 (VCC1), U3.1 (IN), U3.3 (ON/!OFF)
A1/MODULE1: JP4.5, MODULE1_SENSE.3, U1.37 ((ADC6/TDO)PF6), U2.37 ((ADC6/TDO)PF6)
A2/MODULE2: JP4.4, MODULE2_SENSE.3, U1.38 ((ADC5/TMS)PF5), U2.38 ((ADC5/TMS)PF5)
A3: JP4.3, U1.39 ((ADC4/TCK)PF4), U2.39 ((ADC4/TCK)PF4)
A4: JP4.2, U1.40 ((ADC1)PF1), U2.40 ((ADC1)PF1)
A5: JP4.1, U1.41 ((ADC0)PF0), U2.41 ((ADC0)PF0)
AGND: C6.2, R10.1, U1.43 (GND3), U2.43 (GND3)
AREF: C6.1, JP1.3, U1.42 (AREF), U2.42 (AREF)
AVCC: C5.1, L1.2, U1.24 (AVCC), U1.44 (AVCC1), U2.24 (AVCC), U2.44 (AVCC1)
BLED: LED_EXP.4, R2.1, R5.1, TBLUE.P$2
CMP: C22.1, IC2.5 (+IN), RN1.1, RN1.7 (2)
D0/RX: JP2.8, U1.20 ((RXD1/AIN1/INT2)PD2), U2.20 ((RXD1/AIN1/INT2)PD2)
D1/TX: JP2.7, U1.21 ((TXD1/INT3)PD3), U2.21 ((TXD1/INT3)PD3)
D2/SDA: JP1.2, JP2.6, MODULE1_SENSE.1, MODULE2_SENSE.1, U1.19 ((SDA/INT1)PD1), U2.19 ((SDA/INT1)PD1)
D3/SCL: JP1.1, JP2.5, MODULE1_SENSE.2, MODULE2_SENSE.2, U1.18 ((OC0B/SCL/INT0)PD0), U2.18 ((OC0B/SCL/INT0)PD0)
D4: JP2.4, U1.25 ((ICP1/ADC8)PD4), U2.25 ((ICP1/ADC8)PD4)
D5/RED*: JP2.3, TRED.P$1, U1.31 ((OC3A/#0C4A)PC6), U2.31 ((OC3A/#0C4A)PC6)
D6/GREEN*: JP2.2, TGREEN.P$1, U1.27 ((T0/OC4D/ADC10)PD7), U2.27 ((T0/OC4D/ADC10)PD7)
D7/MODULE1: JP2.1, MODULE1_SENSE.4, U1.1 ((INT6/AIN0)PE6), U2.1 ((INT6/AIN0)PE6)
D9/BLUE*: JP1.9, TBLUE.P$1, U1.29 ((PCINT5/OC1A/#OC4B/ADC12)PB5), U2.29 ((PCINT5/OC1A/#OC4B/ADC12)PB5)
D+: J1.P$3 (D+), RN3.8 (2), Z1.1
D-: J1.P$2 (D-), RN3.5 (2), Z2.1
GATE_CMD: IC2.7 (OUT), T1.3 (G)
GLED: LED_EXP.2, R3.1, R6.1, TGREEN.P$2
GND: 2PIN_CONN.PIN2, C1.2, C2.2, C3.1, C4.1, C5.2, C8.-, C9.2, C10.2, C11.2, C13.2, C14.2, C15.2, C22.2, CP1.-, CP2.-, IC1.1 (GND/ADJ), IC2.4 (V-), ICSP.6, IR_CONNECT.P$1 (PIN1), JP1.4, JP3.6, JP3.7, L2.1, MODULE1_PWR.3, MODULE2_PWR.3, PWR_EXP.1, PWR_JACK.P$2, PWR_JACK.P$3, R9.1, R10.2, R11.1, RN1.2 (1), RN1.3 (1), RN2.4 (1), RST.A, RST.B, RST1.A, RST1.B, TBLUE.P$3, TGREEN.P$3, TRED.P$3, U1.15 (GND), U1.23 (GND1), U1.35 (GND2), U1.P$1 (PAD), U2.15 (GND), U2.23 (GND1), U2.35 (GND2), U2.EXP (PAD), U3.2 (GND), U4.GND, U4.GND1 (GND), U4.GND2 (GND), U4.NC, U4.NC1 (NC), U4.NC2 (NC), U4.NC3 (NC), U4.NC4 (NC), U4.NC5 (NC), U4.SGND, Z1.2, Z2.2
HWB: RN1.6 (2), U1.33 ((#HWB)PE2), U2.33 ((#HWB)PE2)
IO8/MODULE2: JP1.10, MODULE2_SENSE.4, U1.28 ((ADC11/PCINT4)PB4), U2.28 ((ADC11/PCINT4)PB4)
IO10*: JP1.8, U1.30 ((PCINT6/OC1B/OC4B/ADC13)PB6), U2.30 ((PCINT6/OC1B/OC4B/ADC13)PB6)
IO11/TSK*: JP1.7, U1.12 ((PCINT7/OC0A/OC1C/#RTS)PB7), U2.12 ((PCINT7/OC0A/OC1C/#RTS)PB7), U4.DIS
IO12: JP1.6, U1.26 ((T1/#OC4D/ADC9)PD6), U2.26 ((T1/#OC4D/ADC9)PD6)
IO13*: JP1.5, U1.32 ((ICP3/CLK0/OC4A)PC7), U2.32 ((ICP3/CLK0/OC4A)PC7)
MISO: ICSP.1, U1.11 ((PD0/MISO/PCINT3)PB3), U2.11 ((PD0/MISO/PCINT3)PB3)
MOSI: ICSP.4, U1.10 ((PDI/MOSI/PCINT2)PB2), U2.10 ((PDI/MOSI/PCINT2)PB2)
unnamed: R8.1, U4.TON
unnamed: D3.A, R9.2, U4.ISEN
unnamed: C12.1, U4.BOOT
unnamed: C12.2, D3.C, I_LEDDRIVER.P$1, U4.LX
unnamed: RN2.7 (2), TX.C
unnamed: RN2.6 (2), RX.C
unnamed: ON.C, RN2.5 (2)
unnamed: R2.2, RGB3.P$1
unnamed: 2PIN_CONN.PIN1, I_LEDDRIVER.P$2
unnamed: R3.2, RGB3.P$2
unnamed: R4.2, RGB3.P$3
unnamed: RGB2.P$1, RGB3.P$6
unnamed: RGB2.P$2, RGB3.P$5
unnamed: RGB2.P$3, RGB3.P$4
unnamed: R5.2, RGB6.P$1
unnamed: R6.2, RGB6.P$2
unnamed: R7.2, RGB6.P$3
unnamed: RGB5.P$1, RGB6.P$6
unnamed: RGB5.P$2, RGB6.P$5
unnamed: RGB5.P$3, RGB6.P$4
unnamed: RGB4.P$3, RGB5.P$4
unnamed: RGB4.P$2, RGB5.P$5
unnamed: RGB4.P$1, RGB5.P$6
unnamed: RGB1.P$3, RGB2.P$4
unnamed: RGB1.P$2, RGB2.P$5
unnamed: RGB1.P$1, RGB2.P$6
PWRIN: D1.A, PWR_EXP.2, PWR_JACK.P$1
RD+: RN3.1, U1.4 (D+), U2.4 (D+)
RD-: RN3.4 (1), U1.3 (D-), U2.3 (D-)
RESET: D2.A, ICSP.5, JP3.3, RN1.4 (1), RST.D, RST.H, RST1.D, RST1.H, U1.13 (RESET), U2.13 (RESET)
RLED: LED_EXP.3, R4.1, R7.1, TRED.P$2
RXLED: RN2.3 (1), U1.8 ((SS/PCINT0)PB0), U2.8 ((SS/PCINT0)PB0)
SCK: ICSP.3, U1.9 ((SCLK/PCINT1)PB1), U2.9 ((SCLK/PCINT1)PB1)
SQUISH: IR_CONNECT.P$2 (PIN2), JP4.6, U1.36 ((ADC7/TDI)PF7), U2.36 ((ADC7/TDI)PF7)
TXLED: RN2.2 (1), U1.22 ((XCK1/#CTS)PD5), U2.22 ((XCK1/#CTS)PD5)
UCAP: C7.1, U1.6 (UCAP), U2.6 (UCAP)
UGND: C7.2, J1.P$5 (GND), L2.2, R11.2, U1.5 (UGND), U2.5 (UGND)
USBID: J1.P$4 (ID)
VIN: C10.1, CP1.+, D1.C, IC1.3 (IN), JP3.8, LED_EXP.1, R8.2, RGB1.P$4, RGB1.P$5, RGB1.P$6, RGB4.P$4, RGB4.P$5, RGB4.P$6, RN1.8 (2), U4.VIN
VUSB: C8.+, C9.1, F1.1, T1.1 (D), U1.7 (VBUS), U2.7 (VBUS)
XTAL1: C4.2, R1.1, U1.17 (XTAL1), U2.17 (XTAL1), X1.1, X1.P$1 (1)
XTAL2: C3.2, R1.2, U1.16 (XTAL2), U2.16 (XTAL2), X1.2, X1.P$2 (2)
XUSB: F1.2, J1.P$1 (VCC)

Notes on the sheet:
IOREF
RGB LED Drivers
Power LED Driver
ATMEGA (AU PACKAGE)
Shield Pin Headers
Module Pin Headers
Squish JST Connector
Module 1 Pin Headers
Module 2 Pin Headers
Not Used
USB
Indicator LEDs
5V Autoselect
Power
Clyde Main Board v1.0 28-05-2014
ATMEGA (MU PACKAGE)
Alternative QFN package.
Both will work on this board,
can base choice on price and availability

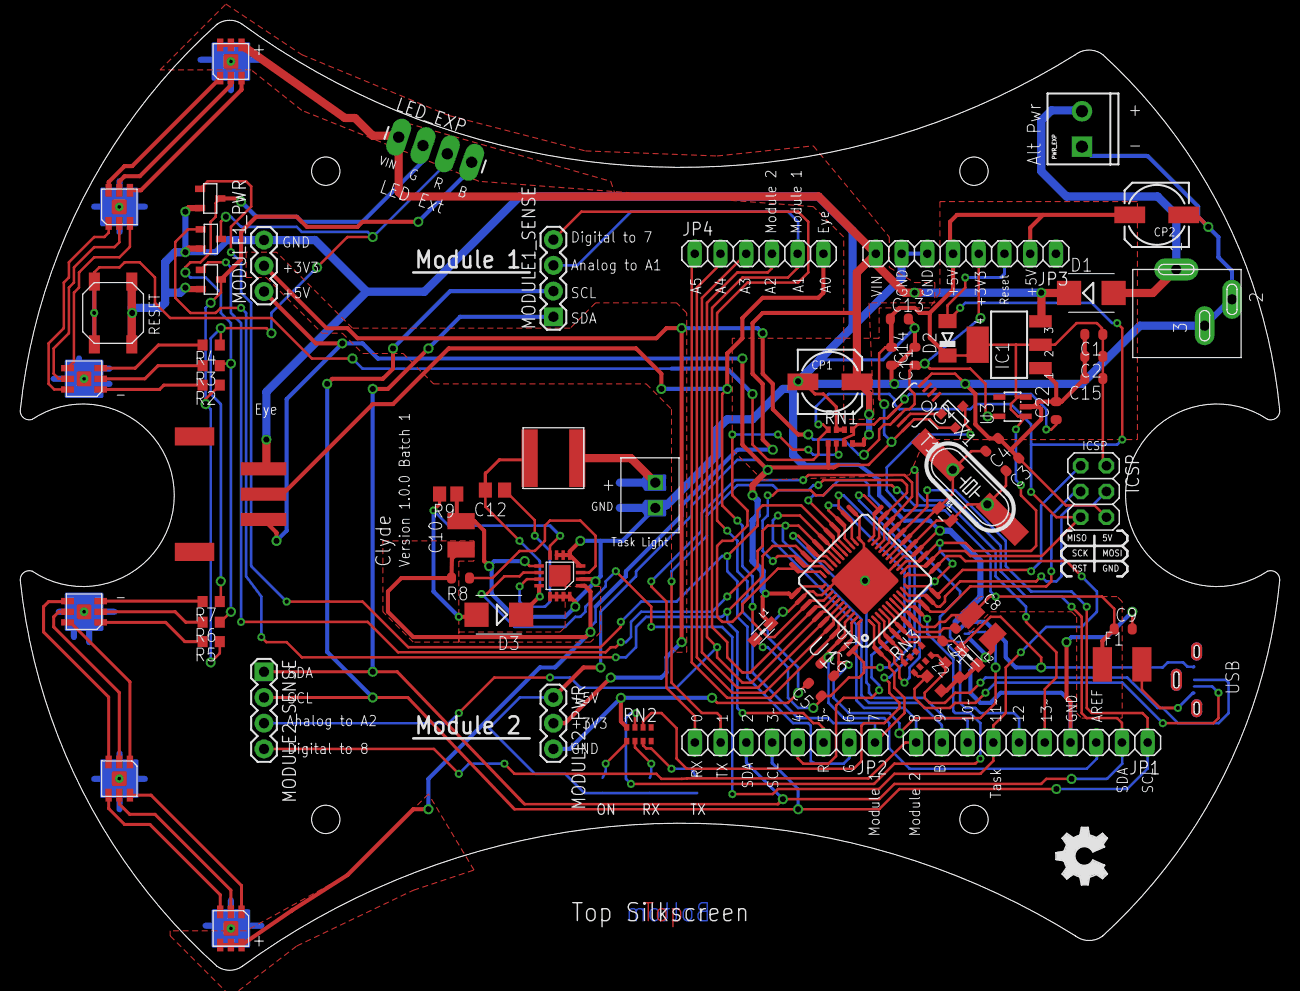
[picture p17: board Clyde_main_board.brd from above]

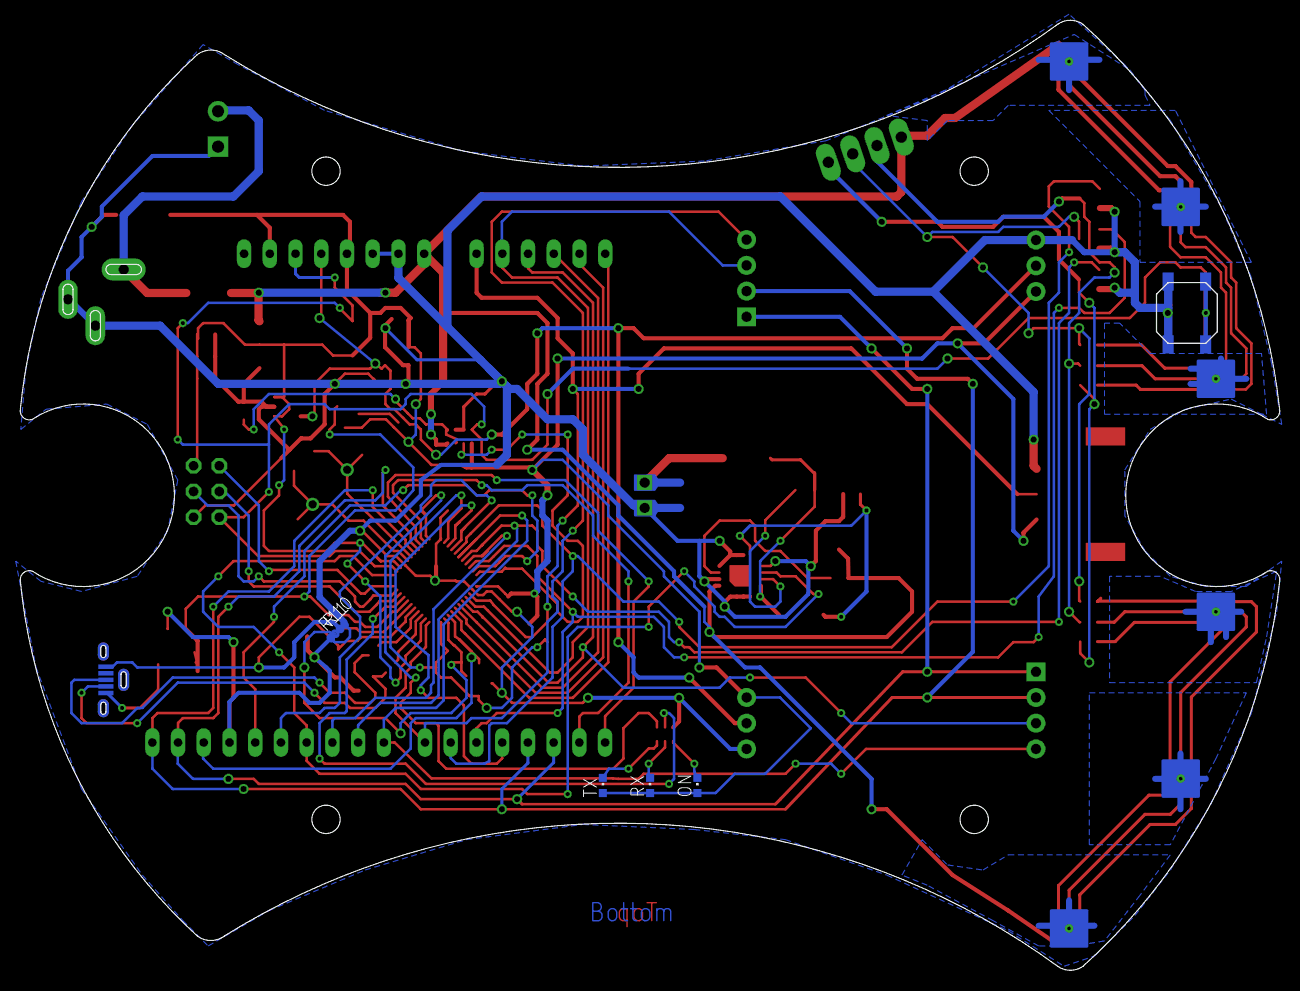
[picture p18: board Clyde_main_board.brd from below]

Board: 2 copper layers, 124.4 x 93.8 mm, 79 parts (7 on the bottom side), 76 nets.

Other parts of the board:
U$1: OSHW_FILLX200_NOTEXT

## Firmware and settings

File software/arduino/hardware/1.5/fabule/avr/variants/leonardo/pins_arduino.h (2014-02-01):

/*
  pins_arduino.h - Pin definition functions for Arduino
  Part of Arduino - http://www.arduino.cc/

  Copyright (c) 2007 David A. Mellis

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
  $Id: wiring.h 249 2007-02-03 16:52:51Z mellis $
*/

#ifndef Pins_Arduino_h
#define Pins_Arduino_h

#include <avr/pgmspace.h>

// Workaround for wrong definitions in "iom32u4.h".
// This should be fixed in the AVR toolchain.
#undef UHCON
#undef UHINT
#undef UHIEN
#undef UHADDR
#undef UHFNUM
#undef UHFNUML
#undef UHFNUMH
#undef UHFLEN
#undef UPINRQX
#undef UPINTX
#undef UPNUM
#undef UPRST
#undef UPCONX
#undef UPCFG0X
#undef UPCFG1X
#undef UPSTAX
#undef UPCFG2X
#undef UPIENX
#undef UPDATX
#undef TCCR2A
#undef WGM20
#undef WGM21
#undef COM2B0
#undef COM2B1
#undef COM2A0
#undef COM2A1
#undef TCCR2B
#undef CS20
#undef CS21
#undef CS22
#undef WGM22
#undef FOC2B
#undef FOC2A
#undef TCNT2
#undef TCNT2_0
#undef TCNT2_1
#undef TCNT2_2
#undef TCNT2_3
#undef TCNT2_4
#undef TCNT2_5
#undef TCNT2_6
#undef TCNT2_7
#undef OCR2A
#undef OCR2_0
#undef OCR2_1
#undef OCR2_2
#undef OCR2_3
#undef OCR2_4
#undef OCR2_5
#undef OCR2_6
#undef OCR2_7
#undef OCR2B
#undef OCR2_0
#undef OCR2_1
#undef OCR2_2
#undef OCR2_3
#undef OCR2_4
#undef OCR2_5
#undef OCR2_6
#undef OCR2_7

#define NUM_DIGITAL_PINS  30
#define NUM_ANALOG_INPUTS 12

#define TX_RX_LED_INIT	DDRD |= (1<<5), DDRB |= (1<<0)
#define TXLED0			PORTD |= (1<<5)
#define TXLED1			PORTD &= ~(1<<5)
#define RXLED0			PORTB |= (1<<0)
#define RXLED1			PORTB &= ~(1<<0)

static const uint8_t SDA = 2;
static const uint8_t SCL = 3;

// Map SPI port to 'new' pins D14..D17
static const uint8_t SS   = 17;
static const uint8_t MOSI = 16;
static const uint8_t MISO = 14;
static const uint8_t SCK  = 15;

// Mapping of analog pins as digital I/O
// A6-A11 share with digital pins
static const uint8_t A0 = 18;
static const uint8_t A1 = 19;
static const uint8_t A2 = 20;
static const uint8_t A3 = 21;
static const uint8_t A4 = 22;
static const uint8_t A5 = 23;
static const uint8_t A6 = 24;	// D4
static const uint8_t A7 = 25;	// D6
static const uint8_t A8 = 26;	// D8
static const uint8_t A9 = 27;	// D9
static const uint8_t A10 = 28;	// D10
static const uint8_t A11 = 29;	// D12

#define digitalPinToPCICR(p)    ((((p) >= 8 && (p) <= 11) || ((p) >= 14 && (p) <= 17) || ((p) >= A8 && (p) <= A10)) ? (&PCICR) : ((uint8_t *)0))
#define digitalPinToPCICRbit(p) 0
#define digitalPinToPCMSK(p)    ((((p) >= 8 && (p) <= 11) || ((p) >= 14 && (p) <= 17) || ((p) >= A8 && (p) <= A10)) ? (&PCMSK0) : ((uint8_t *)0))
#define digitalPinToPCMSKbit(p) ( ((p) >= 8 && (p) <= 11) ? (p) - 4 : ((p) == 14 ? 3 : ((p) == 15 ? 1 : ((p) == 16 ? 2 : ((p) == 17 ? 0 : (p - A8 + 4))))))

//	__AVR_ATmega32U4__ has an unusual mapping of pins to channels
extern const uint8_t PROGMEM analog_pin_to_channel_PGM[];
#define analogPinToChannel(P)  ( pgm_read_byte( analog_pin_to_channel_PGM + (P) ) )

#ifdef ARDUINO_MAIN

// On the Arduino board, digital pins are also used
// for the analog output (software PWM).  Analog input
// pins are a separate set.

// ATMEL ATMEGA32U4 / ARDUINO LEONARDO
//
// D0				PD2					RXD1/INT2
// D1				PD3					TXD1/INT3
// D2				PD1		SDA			SDA/INT1
// D3#				PD0		PWM8/SCL	OC0B/SCL/INT0
// D4		A6		PD4					ADC8
// D5#				PC6		???			OC3A/#OC4A
// D6#		A7		PD7		FastPWM		#OC4D/ADC10
// D7				PE6					INT6/AIN0
//
// D8		A8		PB4					ADC11/PCINT4
// D9#		A9		PB5		PWM16		OC1A/#OC4B/ADC12/PCINT5
// D10#		A10		PB6		PWM16		OC1B/0c4B/ADC13/PCINT6
// D11#				PB7		PWM8/16		0C0A/OC1C/#RTS/PCINT7
// D12		A11		PD6					T1/#OC4D/ADC9
// D13#				PC7		PWM10		CLK0/OC4A
//
// A0		D18		PF7					ADC7
// A1		D19		PF6					ADC6
// A2		D20 	PF5					ADC5
// A3		D21 	PF4					ADC4
// A4		D22		PF1					ADC1
// A5		D23 	PF0					ADC0
//
// New pins D14..D17 to map SPI port to digital pins
//
// MISO		D14		PB3					MISO,PCINT3
// SCK		D15		PB1					SCK,PCINT1
// MOSI		D16		PB2					MOSI,PCINT2
// SS		D17		PB0					RXLED,SS/PCINT0
//
// TXLED			PD5
// RXLED		    PB0
// HWB				PE2					HWB

// these arrays map port names (e.g. port B) to the
// appropriate addresses for various functions (e.g. reading
// and writing)
const uint16_t PROGMEM port_to_mode_PGM[] = {
	NOT_A_PORT,
	NOT_A_PORT,
	(uint16_t) &DDRB,
	(uint16_t) &DDRC,
	(uint16_t) &DDRD,
	(uint16_t) &DDRE,
	(uint16_t) &DDRF,
};

const uint16_t PROGMEM port_to_output_PGM[] = {
	NOT_A_PORT,
	NOT_A_PORT,
	(uint16_t) &PORTB,
	(uint16_t) &PORTC,
	(uint16_t) &PORTD,
	(uint16_t) &PORTE,
	(uint16_t) &PORTF,
};

const uint16_t PROGMEM port_to_input_PGM[] = {
	NOT_A_PORT,
	NOT_A_PORT,
	(uint16_t) &PINB,
	(uint16_t) &PINC,
	(uint16_t) &PIND,
	(uint16_t) &PINE,
	(uint16_t) &PINF,
};
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

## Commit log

2013-10-14 Initial commit of the Clyde repo with bootloader, core and driver based on the Arduino caterina and core version 1.0.5.
    [TcfTransactionLog.csv]
2014-02-01 Moved the firmware from the private to public git. Time to take this baby out! Updated the README with instructions. Added the Arduino IDE addons to add Clyde as a board in the IDE.
    [TcfTransactionLog.csv, eeprom-map.xls]
2014-02-07 Fixed a bug in the eye long press event to blink correctly. Fixed the simple formula to calculate the threshold. Started adding CLYDE_DEBUG output for the eye calibration and press detection. Renamed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
2014-02-14 Changed how the eye calibration handles infrared noise (aka the sun) to be more flexible.
2014-02-14 Changed personality modules detection to the setup phase instead of continuously checking. Fixed a bug init the Touchy-Feely init not setting the pin input mode correctly.
2014-02-24 Updated the VID/PID with values from OpenMoko
2014-02-25 Updated fuses in boards.txt files to not erase EEPROM when burning bootloader. Merged latest firmware and bootloader in the .hex files.
2014-03-17 Started adding control over serial. Merged support for Loudmouth, need to test with final version. Fixed a bug of AoD module that would start sunset cycle when turning off the white light. Changed I2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
2014-05-05 Added signed drivers and installers.
2014-05-05 Removed the I2Cdev library from the Clyde library. It's now in the MPR121 library folder.
2014-05-06 Changed the id value range to match the final resistor.
2014-05-23 Removed the red blinks when the eye is pressed and held. Turns off Clyde instead. Removed the red blinks when IR low levels prevent calibration. Turns off Clyde instead. Adjusted Afraid of the Dark l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
2014-05-30 Added some debug output. Loosened the module id threshold just in case. Adjust the sunset trigger threshold to a better level.
2014-05-30 Added/cleaned debug output. Added reset of the MPR121 when switching the lights on/off to deal with the noise changes. Cleaned up the code checking for touch events and tickle.
2014-05-30 Added/cleaned debug output. Changed the white light pulse when calibration of the eye failed to something less epilepsy inducing.
2014-08-04 Edit readme to include section on Windows drivers
2014-08-09 Update Fabule hardware for Arduino 1.5.7
2014-08-16 Switch to kroimon's Arduino-SerialCommand
    The SerialCommand library included with Clyde has issues
    parsing long strings and is generally flaky. kroimon re-wrote
    SerialCommand to be smaller and less buggy.
    You can see the existing SerialCommand fail by doing sending
    this command to Clyde:
    SET_AMBIENT 100 150 200
    In contrast, the kroimon one just works, and the code is much
    cleaner and compact. :+1:
    See: https://github.com/kroimon/Arduino-SerialCommand
2014-08-21 Add hardware schematics
    [Clyde_main_board.brd, Clyde_main_board.sch, afraid_of_the_dark.brd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]

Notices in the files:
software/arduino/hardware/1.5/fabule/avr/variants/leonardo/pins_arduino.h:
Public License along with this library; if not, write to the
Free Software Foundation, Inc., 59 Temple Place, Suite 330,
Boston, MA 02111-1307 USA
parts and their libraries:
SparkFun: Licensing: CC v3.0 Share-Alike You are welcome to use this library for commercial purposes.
